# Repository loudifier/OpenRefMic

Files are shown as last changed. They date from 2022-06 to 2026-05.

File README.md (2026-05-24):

# OpenRefMic



OpenRefMic is an open hardware design for a reference microphone that fits in the popular 1/2" reference microphone form factor, works with consumer microphone interfaces, and meets or exceeds the performance of professional reference microphones at a vastly reduced total system cost.

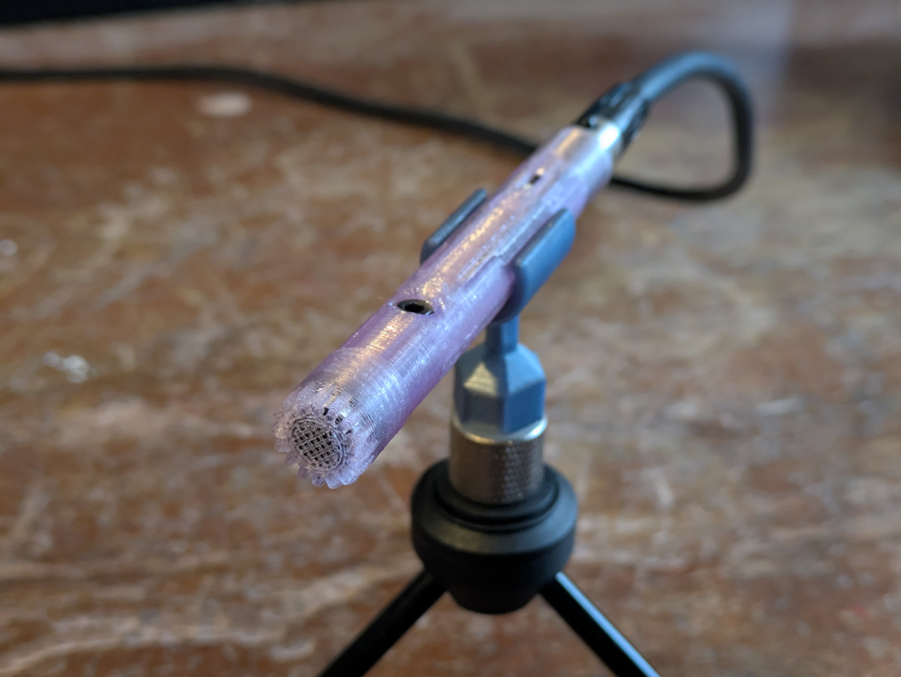
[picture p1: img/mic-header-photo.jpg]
OpenRefMic


<br>

## OpenRefMic v2

OpenRefMic version 2 significantly improves the usability of the mic, with integrated frequency response correction, improved PCB layout, and a simpler and more robust mechanical design.

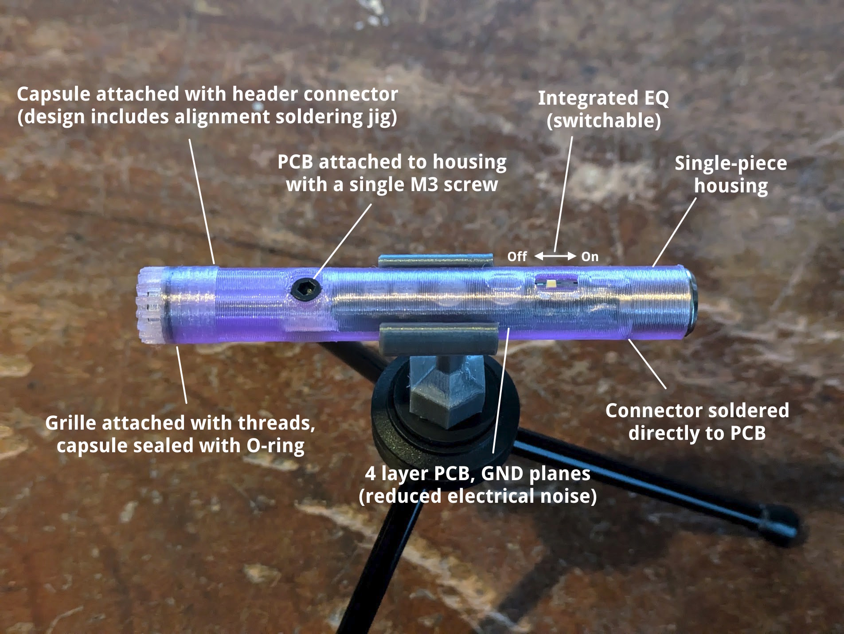
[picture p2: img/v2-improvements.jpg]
v2 improvements


<br>

## Critical specs, typical performance

- Frequency Response: 10Hz-20kHz
    - ±1dB from 10Hz 2.5kHz
    - +4-7dB 10Hz-20kHz raw capsule response
    - ±2dB 10Hz-20kHz with integrated EQ filter
- Noise Floor: 17dBA
- Acoustic Overload Point: 118dBSPL
- Sensitivity: 100mV/Pa
- Dimensions: 12.7x92mm
- Parts cost: $50 (not including 3D printed parts)
- Interface: mini-XLR, 48V phantom power

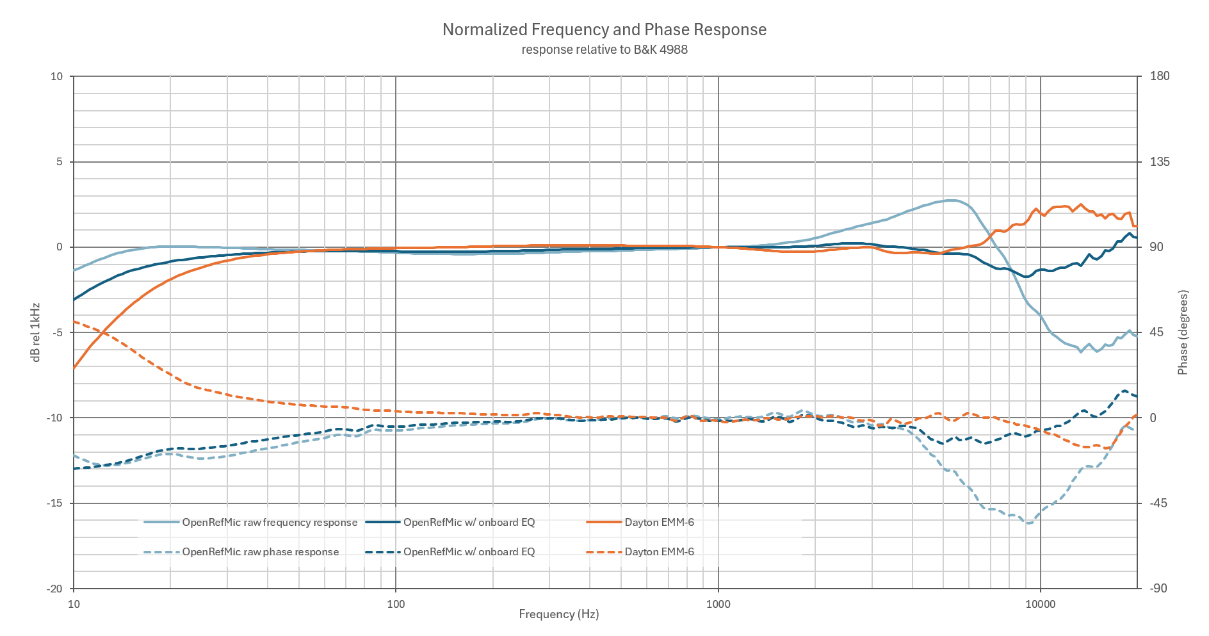
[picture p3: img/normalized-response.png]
normalized frequency response


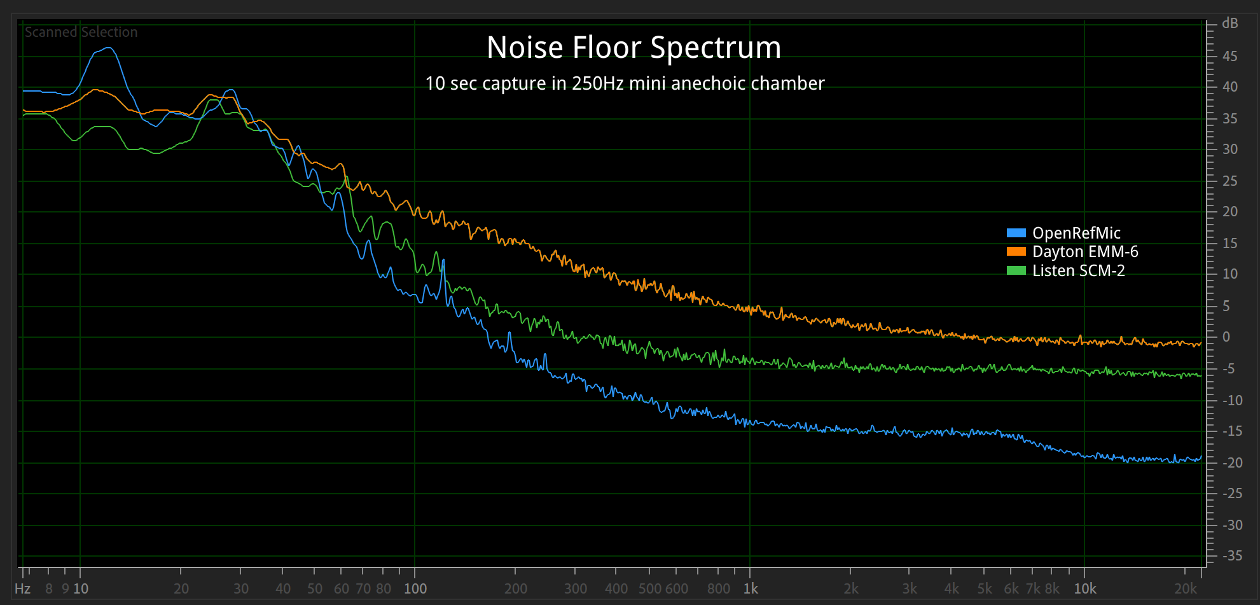
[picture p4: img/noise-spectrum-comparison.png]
noise floor spectrum


<br>

### 1/2" microphone comparison

| Mic | Interface | Frequency Response (20-20k) | Noise Floor | AOP | Price |
|---|---|---|---|---|---|
| OpenRefMic | 48V phantom power, mini XLR | +3/-7dB (±2dB with EQ) | 17dBA | 118dBSPL | Typically <$60 |
| Dayton EMM-6 | 15-48V phantom power, XLR | ±2dB | 36dBA | 127dBSPL | $60 |
| MiniDSP U-MIK 2 | USB-C | Not specified (likely ±2dB) | 20dBA | 125dBSPL | $195 + import |
| PCB 376A32 | 12-48V phantom power, XLR | ±2dB | 15.5dBA | 137dBSPL | $1,445 |
| B&K 4191 | 200V Lemo | <±1dB | 20dBA | 162dBSPL | Ask for price ($$$) |
| GRAS 46AE | CCP BNC | ±2dB | 17dBA | 138dBSPL | Ask for price ($$$) |

<br>

## Project Overview
The core of the OpenRefMic design is a preamplifier that biases an electret microphone from 48V phantom power, buffers the microphone signal, applies a frequency response correction filter, and to sends the signal to a standard microphone interface. The circuit was designed for the [PUI AOM-5024L-HD-F-R](https://puiaudio.com/file/specs-AOM-5024L-HD-F-R.pdf) low noise microphone capsule, and has been built and tested with that part, but should work with most other electret mics. The schematic and PCB layout were designed in KiCAD and are available in the [Preamplifier section](preamplifier/PREAMPLIFIER.md) of the project, along with the [BOM for all electrical and mechanical parts](Bill_of_materials.csv).

<br>

OpenRefMic construction is simple, consisting of a 3D printed housing, the PCB, mic capsule, screw/nut, and optionally an O-ring and dab of UV cure glue. CAD in Fusion360 and STEP formats are in the [Assembly section](assembly/ASSEMBLY.md), along with STLs for the printed parts and a step-by-step construction guide.

<br>

The noise performance of the complete OpenRefMic prototype far exceeds that of comparably-priced measurement microphones, with a flat frequency response suitable as a reference microphone for measuring speakers, distortion, noise emissions, and capturing field recordings. Raw measurement data, compensation curves, and recommendations for applying calibrations to measurements and recordings are in the [Calibration section](calibration/CALIBRATION.md).

<br>

## Project Goals

### Low noise

This is the most important factor of the OpenRefMic project, and all of the other performance metrics and goals are considered "nice to have". While there are several popular affordable measurement microphones on the market (like the Dayton EMM-6), their noise performance ranges from mediocre to poor. Even professional reference microphones tend to prioritize frequency response flatness over noise performance, and very low noise reference microphones are prohibitively expensive for the hobbyist or self-funded experimenter. The video below is an example of the dramatic difference in noise performance between OpenRefMic and the Dayton EMM-6.

[field recording noise comparison](https://user-images.githubusercontent.com/23405416/175431344-0c36cc5d-fb55-48f4-8029-bcf0d835c0a0.mp4)

Low noise is obviously helpful for applications like field recordings or measuring low-level noise emissions, but one area where microphone noise floor is often overlooked is in speaker distortion measurements. Increasing the stimulus and analysis window or moving the microphone closer to the speaker can help resolve lower distortion levels, but those options may not always be feasible for the given speaker or test setup. The graph below is an example of the differences that you might see between distortion measurements with a typical budget measurement mic with a ~34dBA noise floor and an OpenRefMic with ~18dBA noise floor.

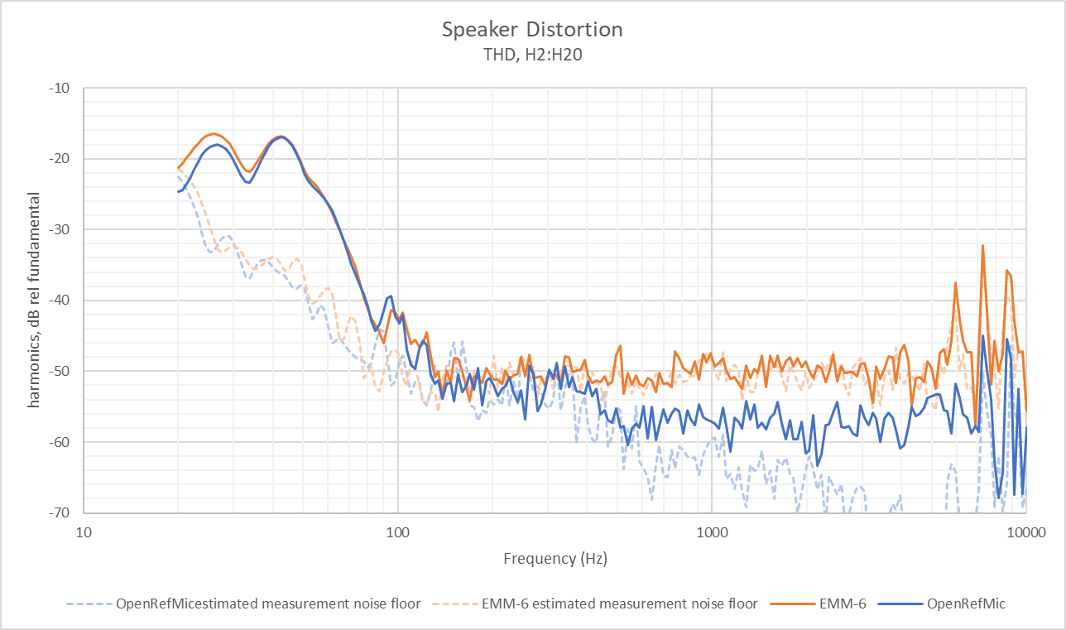
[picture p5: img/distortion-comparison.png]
distortion measurement with OpenRefMic vs EMM-6


<br>

### Flat, omnidirectional frequency response

A reference microphone should have a frequency response that is flat or characterized well enough that it can be understood how measurements and recordings relate to absolute physical constants. Some aberrations in the off-axis response is expected, particularly at very high frequencies, but the design of the housing, porting, and front grille should minimize directional effects as much as possible. In cases where a flat frequency response is not achievable, the response should be characterized and a process should be defined to apply reciprocal filters to correct recordings.

The microphone element in OpenRefMic has a very low noise floor, but it does not have a flat frequency response. See the calibration page for a compensation curve and filter settings to correct measurements and recordings. 

<br>

### Compatibility with "prosumer" audio interfaces

Professional reference microphones typically require interfaces that are uncommon outside of labratory settings. IEPE current loops over BNC cables on the more affordable end of the spectrum and 200V polarization supplied via LEMO connectors at the other end, where the cable itself is often over $500. The pro audio world has instead standardized on balanced signals and phantom powering over cheap XLR cables, and OpenRefMic is designed to achieve high performance with these affordable interfaces.

<br>

### Low cost

Compatibility with consumer-grade microphone interfaces eliminates the prohibitive costs of an IEPE or LEMO interface, but the parts availability and BOM cost of the microphone itself should be comparable to that of measurement microphones that target the DIY speaker building market. The parts needed to build an OpenRefMic are cheap and, with the low prices of desktop 3D printers and PCB fabrication services, many builders will be able to make their own OpenRefMic for less than they would spend on a budget measurement microphone.

<br>

### 1/2" form factor

Many measurement microphones fit a 1/2" cylindrical form factor, or at least have a long probe end with a 1/2" diameter, which helps maintain omnidirectional frequency response up to several kilohertz. Phantom powering necessitates relatively large capacitors, but the OpenRefMic PCB just barely fits within a 1/2" cross-section. Using a mini-XLR connector, the overall microphone dimensions are 12.7x92mm, almost identical to a reference microphone from B&K or GRAS.

Note that the front grille diameter for OpenRefMic v2 is 13.2mm, which is the de facto standard for professional reference microphones. The slightly increased diameter allows enough space to include an O-ring to seal the mic capsule, threads to actually attach the grille to the mic body, and is wide enough to properly seal to a standard 1/2" pistonphone calibrator.

Specialized shapes for specific applications are left up to individual builders, but please share your design if you would like to add additional form factors to the project.

<br>

### Further goals

- The initial design is based around the PUI AOM-5024L-HD-F-R electret microphone capsule, but designs for additional capsules that trade noise performance for frequency response flatness will be added in the future. The preamplifier as-shown should work with a wide variety of electret mics, and component values can be adjusted for optimal performance or compatibility with analog MEMS mics.
- OpenRefMic prototypes have had normalized frequency respone within ±2dB up to 20kHz, which is typical for commercial measurement microphones. However, absolute sensitivity varies by up to ±3dB, which could introduce significant error in SPL measurements. Professional measurement microphones are calibrated in the field with a pistonphone, a device that you insert the microphone tip into, which generates a tone with a precise frequency and sound pressure level that is consistent for a given sealed air volume. If you have any ideas for a device that could replicate this functionality, or otherwise accurately generate or measure a sound pressure level in order to calibrate an OpenRefMic, please reach out.

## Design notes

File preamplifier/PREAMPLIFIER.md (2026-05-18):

# Preamplifier

A high performance mic element determines the majority of the acoustic characteristics of a measurement microphone, but for the hobbyist or experimenter on a budget, actually powering and getting a useful signal from the mic element can be difficult. A power supply with low acoustic and electrical noise is required, as well as a data acquisistion system that can capture the full dynamic range of the transducer, particularly the lowest signal levels. Modern consumer or "pro audio" equipment (not to be confused with "professional" equipment for measuring products under development against telephony standards, for example) is available with excellent performance and very affordable pricing, but cannot directly power an electret mic or get an optimal signal level from it.

The preamplifier is the heart of the OpenRefMic project, powering an electret microphone from a standard 48V phantom power supply, correcting the capsule frequency response, and buffering the mic signal to drive a typical low impedance microphone input.

<br>

## Schematic, layout, project files

The preamplifier schematic in PDF format can be found [here](OpenRefMic_v2-schematic.pdf), and the KiCAD project files and gerbers are [here](ref_mic/gerbers/). The complete bill of materials (including optional and mechanical parts) is [here](../Bill_of_materials.csv).

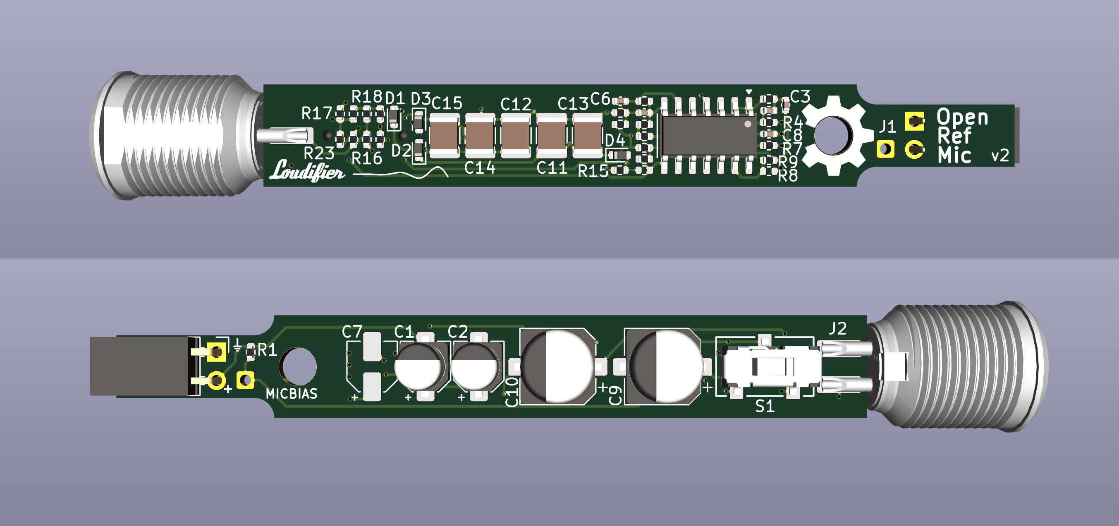
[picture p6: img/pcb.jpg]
PCB


### PCB thickness

Note that the OpenRefMic v2 PCB design uses a mini XLR connector with the terminals soldered to either side of the PCB. A standard 1.6mm/63mil PCB is slightly too thick to fit beteen the terminals of the connector, so a thinner stackup is required. The next common size down from typical vendors like JLCPCB is 1.2mm, which has been tested and works well on the v2 prototype mics.

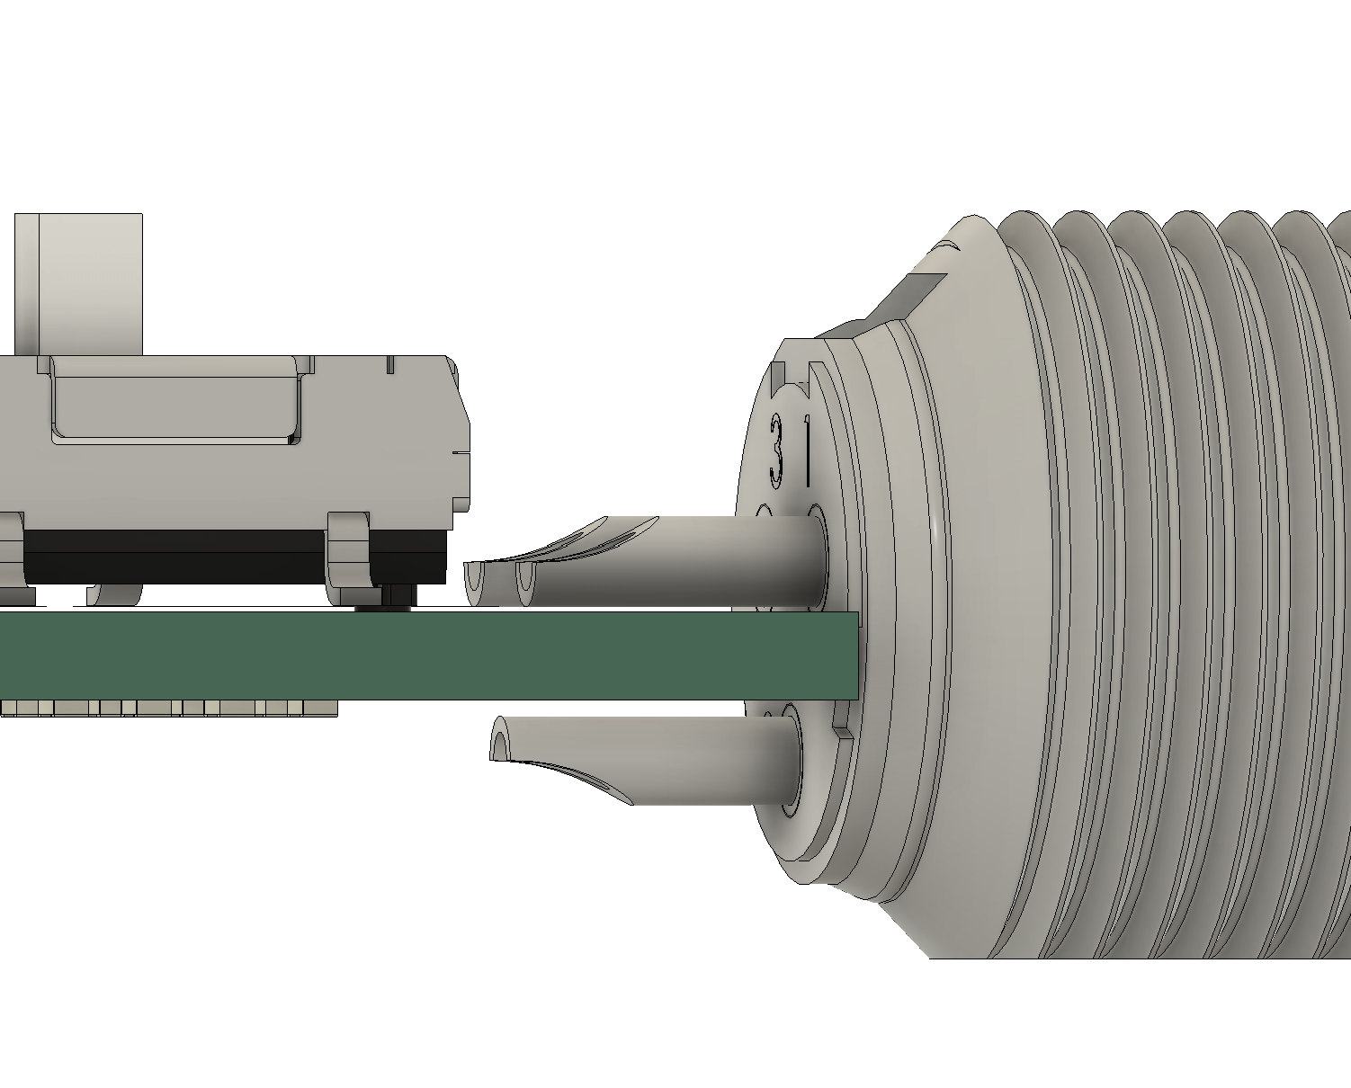
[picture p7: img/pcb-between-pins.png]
PCB between mini XLR connector pins


<br>

## Circuit description

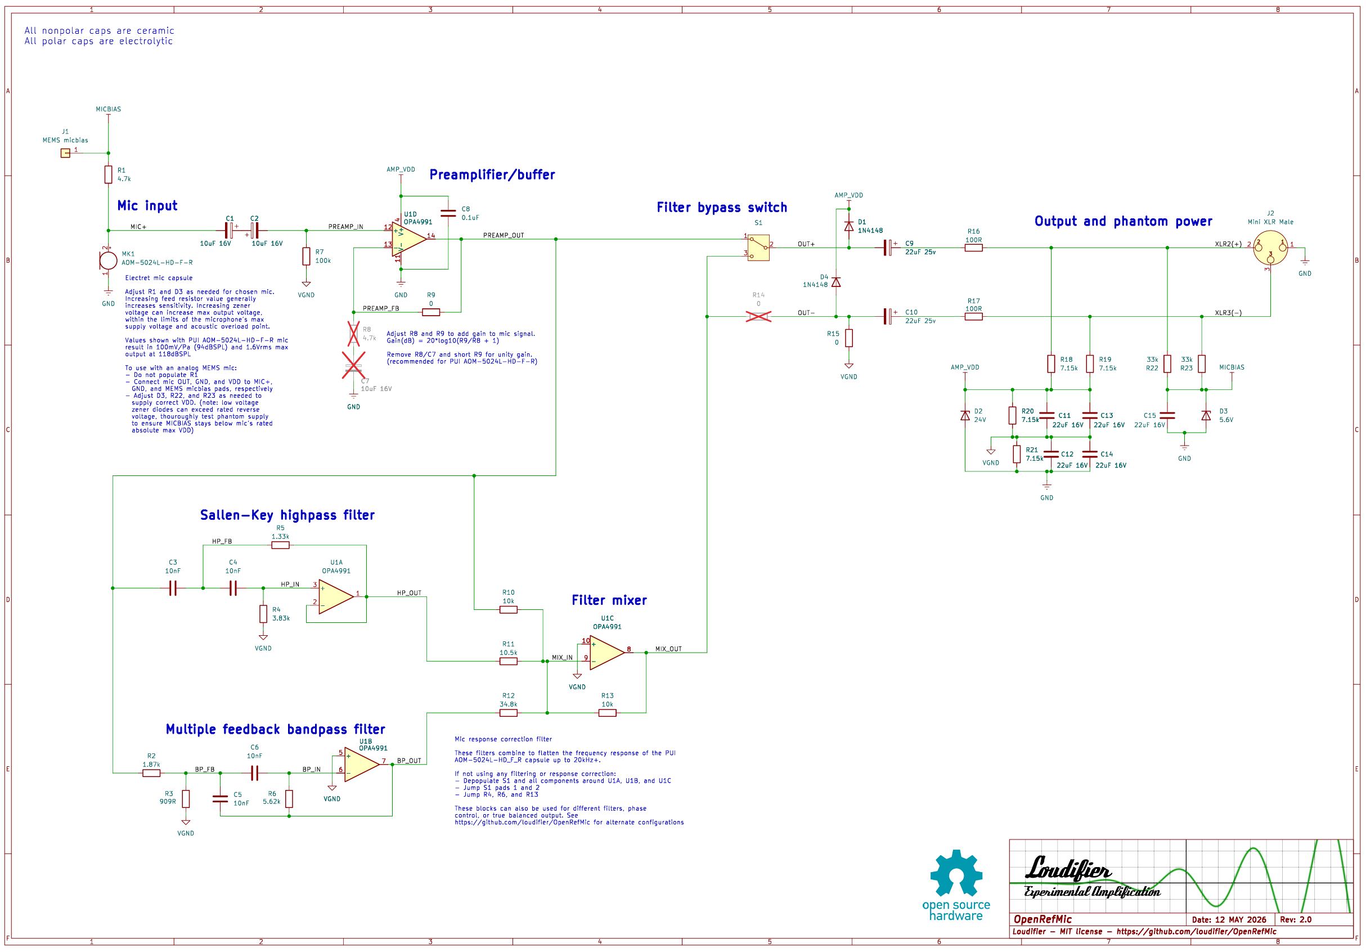
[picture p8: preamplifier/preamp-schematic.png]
preamlifier schematic


### Power

Phantom power is supplied from the host microphone interface in the form of 48VDC connected to each signal line of the balanced cable via 6.81k resistors. The OpenRefMic preamplifier creates two power rails from the phantom power with simple Zener shunt voltage regulators.

The opamp power rail is fed from the phantom power supply through R18 and R19. The actual opamp supply voltage depends on the opamp current draw and the VGND voltage divider formed by R20 and R21, and C11-C14 provide bulk capacitance and low AC impedance for the VGND. OPA4991 is recommended for its low noise and low quiescent current, resulting in an opamp supply rail around 18V. When power is applied, or in the event the opamp current draw is very low or missing, D2 clamps the opamp supply rail to 24V.

D1 and D4 protect the opamp when phantom power is initially applied. When all of the capacitors are discharged and phantom power is turned on, it would briefly apply 48V to the opamp output, until the AC-coupling caps charge up. Instead, the D1 and D4 shunt the voltage at the opamp output to the opamp supply rail, and any voltage at the supply rail over 24V is in turn shunted through D2.

The electret mic bias voltage is fed from the power supply through R22 and R23, with D3 and C15 regulating the shunt voltage.

Electret microphones use a single pin for power input and signal output. They are fairly tolerant of different bias voltages and feed resistances, but ~3V supplied through a 2.2k resistor is common. The feed resistor creates a voltage divider with the microphone's output impedance, so the sensitivity can be increased by increasing the feed resistance. The bias voltage determines the microphone's maximum peak to peak output voltage, so increasing the bias voltage can raise the effective acoustic overload point of the mic. The transducer itself will limit the absolute AOP, but increasing the bias voltage can provide some electrical headroom, particularly when increasing the feed resistance for higher sensitivity.

With 5.6V bias and 4.7k feed resistor, R1, the AOM-5024L-HD-F-R has a voltage sensitivity of about 1V/Pa and an AOP of 118dBSPL. This voltage range matches well with the dynamic range of most microphone inputs, and almost perfectly matches the dynamic range of the popular Focusrite Scarlett 2i2 mic input at the minimum gain setting.

### Buffer and balanced output

An opamp is not strictly necessary to connect the output of an electret mic to a microphone input, but some sort of buffer is needed if you want to maintain a balanced output impedance and high rejection ratio for any common mode noise that is picked up in the cabling. Buffering the signal also avoids loading the electret mic output with the low impedance input of the microphone interface.

U1D is configured as a unity gain buffer. C1 and C2 AC-couple the electret mic signal to the opamp input, and R7 provides DC bias. The mic bias supply and VGND bias may be around the same DC voltage, so C1 and C2 are arranged with opposing polarities to form a nonpolar cap. To increase the buffer gain, increase the value of R9 and populate R8 and C7. To avoid low frequency roll off, the value of R8 should not be reduced below 4.7k.

C9 AC-couples the opamp (or filter mixer) output. 22uF ensures flat frequency response below 10Hz with low impedance microphone interfaces. R16 provides some isolation from the opamp output and capacitive cable loads.

R15, C10, and R17 appear useless at first glance, but are present to match the impedance of the noninverting output. This is not true differential signaling, but it is technically balanced, often called pseudodifferential. As long as both noninverting and inverting signal lines are terminated with matched impedances, EMI picked up by the cable will be equal on both lines and will be canceled by the microphone input.

### Frequency response correction filters

The AOM-5024L-HD-F-R mic capsule has a very low noise floor, but deviates from a flat frequency response at higher frequencies. This response is fairly consistent, and can be corrected to within a couple dB of flat with a carefully arranged filter network. That correction can often be applied as a postprocessing step (see [calibration](../calibration/CALIBRATION.md)), but v2 of the OpenRefMic preamplifier includes an analog filter netowrk that can correct the response for situations where postprocessing is cumbersome or impossible.

The AOM-5024L-HD-F-R response has a resonant peak around 5.5kHz with an attenuated high shelf that flattens out above 14kHz. The high shelf response is corrected by summing a highpassed copy of the micropohne signal (which has inverted polarity at high frequencies) with the unfiltered microphone signal. That leaves a notch in the response, which is corrected by adding an additional bandpassed copy of the signal.

<!--TODO: add graphs for raw and corrected response and individual filters-->

The highpass response is realized with a Sallen-Key filter around U1A, and the bandpass response is formed by a multiple feedback bandpass filter around U1B. U1C acts as an inverting mixer, with R10-R13 adjusting the gain/mixing ratios of the filtered and unfiltered signals. This means the phase of the overall microphone response with frequency response correction is inverted, relative to the microphone capsule phase. This is usually easily corrected with a single button in hardware or software interfaces designed to receive microphone input.

The exact filter parameters and component values were arrived at through simulation, filter calulators, and an optimization script to fit the filters to a target correction curve. See the [calibration section](../calibration/CALIBRATION.md) for details on the filter optimization process.

S1 allows selection between the raw microphone signal and the microphone signal with frequency response correction applied.

## Alternate filter configurations
note: these screenshots were made with an earlier version of the schematic that used incorrect filter component values

### No filter, true balanced output
If you are using the OpenRefMic preamplifier with a different mic capsule that does not need frequency response correction, you can eliminate the filter blocks and filter bypass switch.

- Remove S1, and jump S1 pads 1 and 2
- Most of the components around U1A, U1B, and U1C are not necessary, but R4, R6, and R13 should be populated to avoid unpredictable behaviour

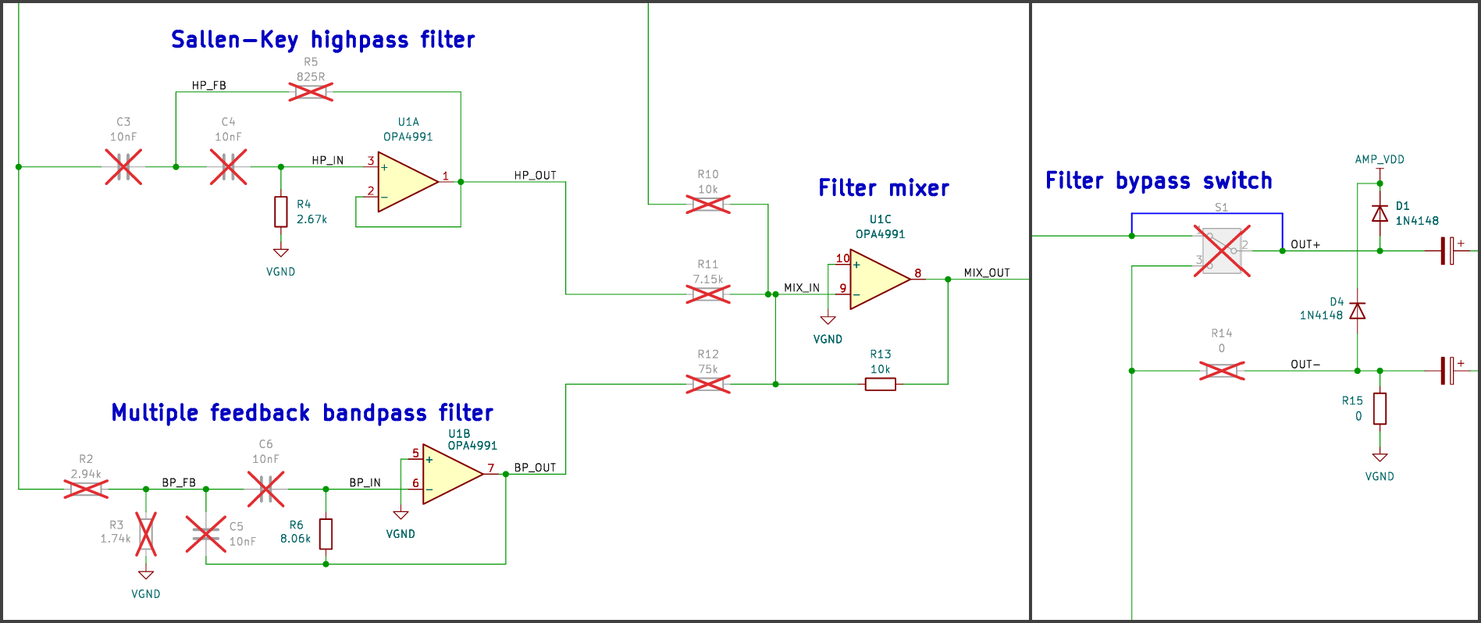
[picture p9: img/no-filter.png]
No filter


To add an inverted signal for true balanced ouptut:

- Remove R11, R12, and R15
- Populate R10, R13, and R14

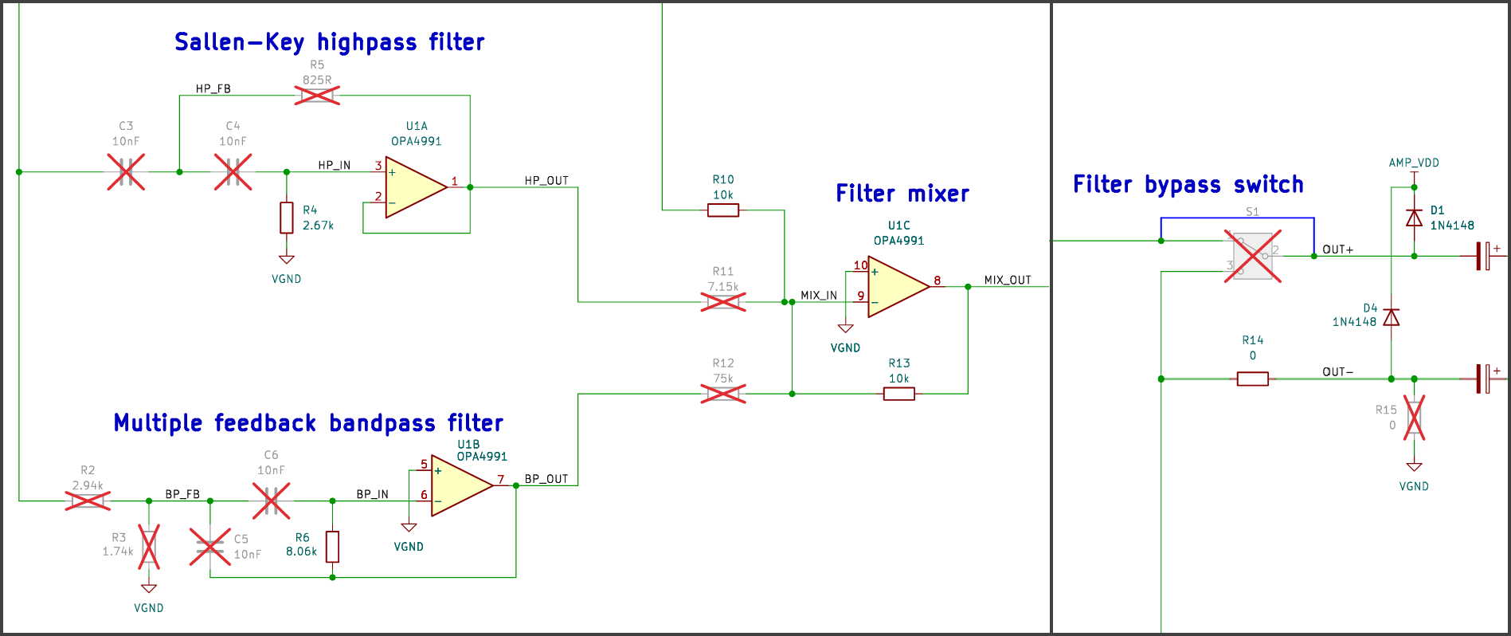
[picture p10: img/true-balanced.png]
True balanced output


Note that the effective ouptut amplitude is 6dB higher with balanced output, so you may need to reduce the value of R1 and/or voltage of D3 to ensure sufficient headroom with your micropohne interface.

### Phase switch

If you need phase control more than frequency response correction, S1 can repurposed to select between noninverted and inverted output.

- Remove R11 and R12

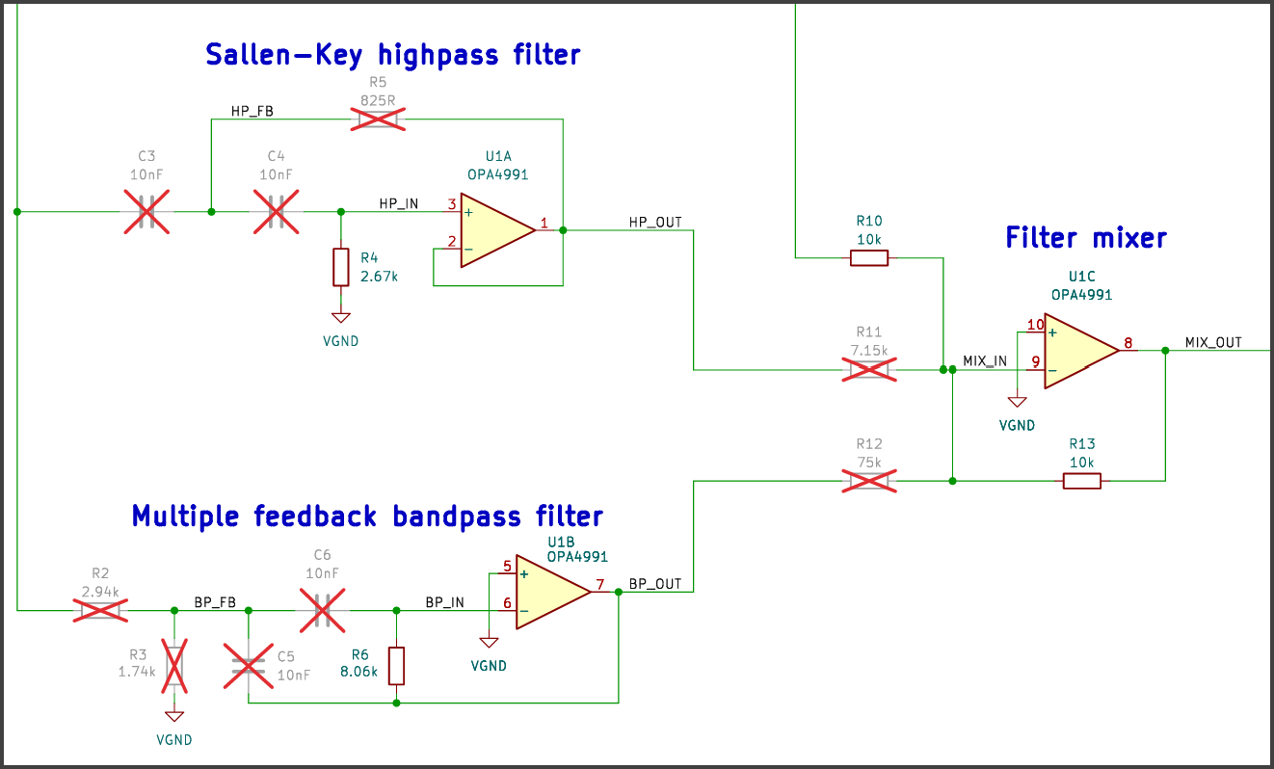
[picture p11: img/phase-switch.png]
Phase inversion switch


### Rumble filter

For a switchable highpass filter to remove rumble below 100Hz:

- Remove R10 and R11
- Replace R6 with a 330k resistor
- Replace R3 with a 75k resistor
- Replace R2 with a 10nF capacitor
- Replace R12 with a 10k resistor

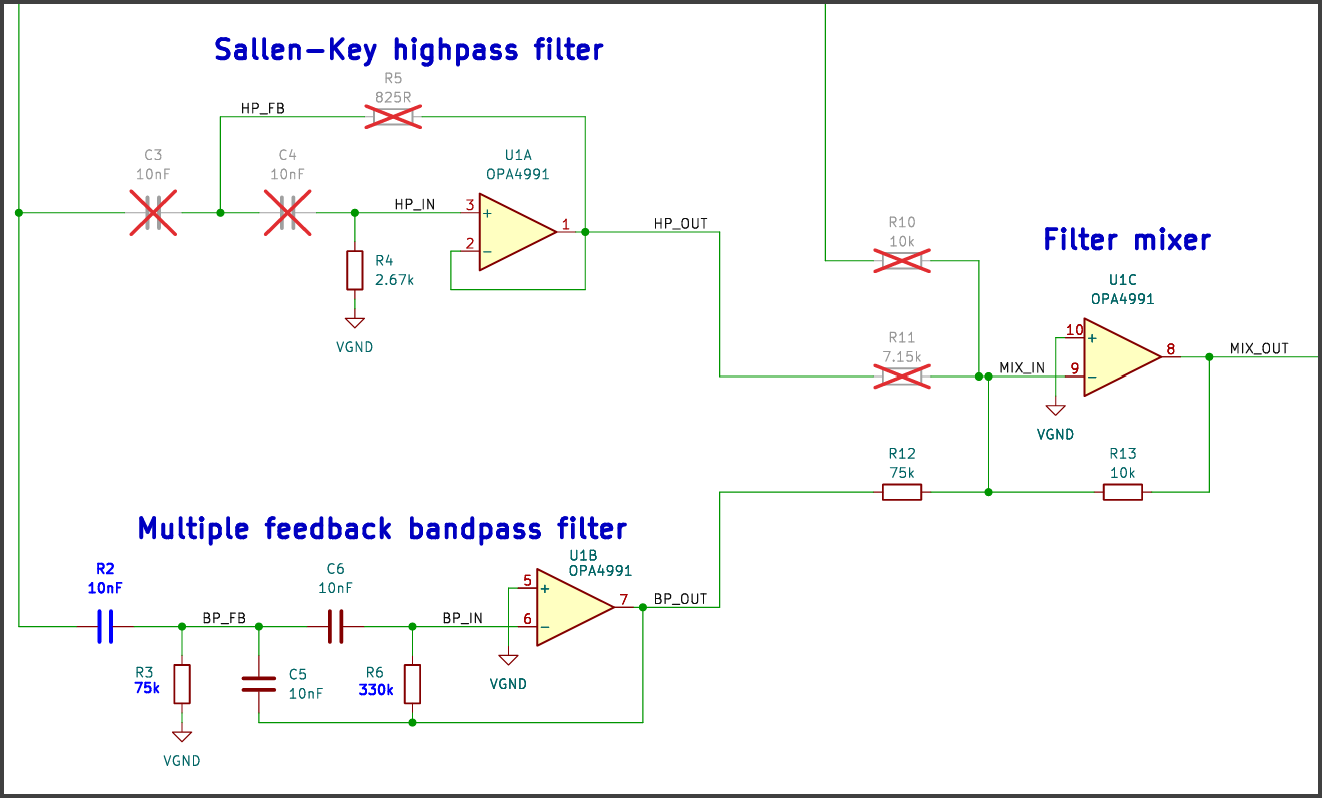
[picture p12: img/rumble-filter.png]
Rumble filter


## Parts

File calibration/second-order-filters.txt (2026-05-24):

2nd order filters to correct OpenRefMic recordings

96kHz Filter parameters
High Shelf
freq: 8291
Q: 0.978
gain: 5.54

Peaking EQ
freq: 4932
Q: 1.029
gain: -3.05

96kHz Biquad filter coefficients
High Shelf
a0	1
a1	-1.240981611
a2	0.536671857
b0	1.70667411
b1	-2.480292285
b2	1.069308421

Peaking EQ
a0	1
a1	-1.602317261
a2	0.689581899	
b0	0.954039842
b1	-1.602317261
b2	0.735542057

48kHz Filter parameters
High Shelf
freq: 6180
Q: 1.323
gain: 5.94

Peaking EQ
freq: 7314
Q: 1.149
gain: -6.12

48kHz Biquad filter coefficients
High Shelf
a0	1
a1	-0.903894843
a2	0.532359656
b0	1.69313323
b1	-2.09951966
b2	1.034851243

Peaking EQ
a0	1
a1	-0.764417706
a2	0.327926396
b0	0.83006978
b1	-0.764417706
b2	0.497856615

44.1kHz Filter parameters
High Shelf
freq: 6135
Q: 1.295
gain: 5.89

Peaking EQ
freq: 5500
Q: 1.2
gain: 5.5

44.1kHz Biquad filter coefficients
High Shelf
a0	1
a1	-0.800182225
a2	0.506962568
b0	1.659071224
b1	-1.919324185
b2	0.967033304

Peaking EQ
a0	1
a1	-0.663683189
a2	0.293674991
b0	0.820807586
b1	-0.663683189
b2	0.472867406

16kHz Filter parameters
High Shelf
freq: 7521
Q: 0.888
gain: 13.72

Peaking EQ
freq: 4792
Q: 0.631
gain: -3.33

16kHz Biquad filter coefficients
High Shelf
a0	1
a1	1.851899488
a2	0.86692061
b0	1.094511024
b1	1.822962161
b2	0.801346913

Peaking EQ
a0	1
a1	0.319816173
a2	0.045056489
b0	0.847950826
b1	0.319816173
b2	0.197105663

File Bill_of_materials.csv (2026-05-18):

Electrical components
Reference | Value | Qty | DNP | DigiKey_Part_Number | LCSC_Part_Number | Comment
C1,C2 | 10uF 16V | 2 |  | UZG1C100MCL1GB | Lelon VSS100M1CTR-0404
C3,C4,C5,C6 | 10nF | 4 |  | CC0402KRX7R9BB103 | YAGEO CC0402KRX7R9BB103
C7 | 10uF 16V | 1 | DNP | UZG1C100MCL1GB | Lelon VSS100M1CTR-0404 | Populate R8 and C7 to increase gain
C8 | 0.1uF | 1 |  | CC0402KRX5R9BB104 | YAGEO CC0402KRX5R9BB104
C9,C10 | 22uF 25v | 2 |  | UZG1E220MCL1GB | Nichicon UZG1E220MCL1GB
C11,C12,C13,C14,C15 | 22uF 16V | 5 |  | EMK325BJ226MD-T | Taiyo Yuden EMK325BJ226MD-T
D1,D4 | 1N4148 | 2 |  | 1N4148X-TP | MCC 1N4148X-TP
D2 | 24V | 1 |  | BZT585B24T-7 | Diodes Incorporated BZT585B24T-7 | Zener diode
D3 | 5.6V | 1 |  | BZT52C5V6T-7 | Diodes Incorporated BZT52C5V6T-7 | Zener diode
J2 | Mini XLR Male, panel mount | 1 |  | TB3M | Switchcraft TB3M (not normally stocked) | Significantly cheaper no-name alternatives available on Amazon/AliExpress
MK1 | AOM-5024L-HD-F-R | 1 |  | AOM-5024L-HD-F-R | PUI Audio, Inc. AOM-5024L-HD-F-R (not normally stocked)
R1 | 4.7k | 1 |  | RC0402FR-074K7L | YAGEO RC0402FR-074K7L
R8 | 4k7 | 1 | DNP | RC0402FR-074K7L | YAGEO RC0402FR-074K7L | Populate R8 and C7 to increase gain
R2 | 1.87k | 1 |  | RC0402FR-131K87L | YAGEO RC0402FR-131K87L
R3 | 909R | 1 |  | RC0402FR-07909RL | YAGEO RC0402FR-07909RL
R4 | 3.83k | 1 |  | RC0402FR-073K83L | YAGEO RC0402FR-073K83L
R5 | 1.33k | 1 |  | RC0402FR-131K33L | YAGEO RC0402FR-131K33L
R6 | 5.62k | 1 |  | RC0402FR-075K62L | YAGEO RC0402FR-075K62L
R7 | 100k | 1 |  | RC0402FR-07100KL | YAGEO RC0402FR-07100KL
R9,R15 | 0 | 2 |  | RC0402JR-070RL | YAGEO RC0402JR-070RL
R14 | 0 | 1 | DNP | RC0402JR-070RL | YAGEO RC0402JR-070RL | When not using correction filtering, R14 can be populated for true balanced output (see OpenRefMic project repository for alternate configurations)
R10,R13 | 10k | 2 |  | RC0402FR-0710KL | YAGEO RC0402FR-0710KL
R11 | 10.5k | 1 |  | RC0402FR-0710K5L | YAGEO RC0402FR-0710K5L
R18,R19,R20,R21 | 7.15k | 4 |  | RC0402FR-077K15L | YAGEO RC0402FR-077K15L
R12 | 34.8k | 1 |  | RC0402FR-0734K8L | YAGEO RC0402FR-0734K8L
R16,R17 | 100R | 2 |  | RC0402FR-07100RL | YAGEO RC0402FR-07100RL
R22,R23 | 33k | 2 |  | RC0402FR-0733KL | YAGEO RC0402FR-0733KL
S1 | CL-SB-12B-01T | 1 |  | CL-SB-12B-01T | Nidec CL-SB-12B-01T | Switch, single pole double throw
U1 | OPA1664 | 1 |  | OPA1664AIDR | TI OPA1664AID | Can substitute with other quad opamp with SOIC-14 package and <~4mA total quiescent current
-- | 1x2 2.54mm RA female header | 1 |  | PPPC021LGBN-RC | CJT(Changjiang Connectors) A2541HWR-2P | Install in MK1 pads on PCB
-- | 1x2 2.54mm RA male header | 1 |  | 10129379-902002BLF | XFCN PZ254R-11-02P | Plug into female header, align mic capsule, and solder male pins to mic capsule (see assembly instructions)
Mechanical components | Part | Qty |  | McMaster_Part_Number |  | Comment
 | M3x8 screw | 1 |  | 91290A113
 | M3 nut | 1 |  | 98676A100
 | 10.5x1.0mm O-ring | 1 |  | 9262K612 |  | Fit into groove on interior surface of grille, seals around outside of mic capsule
3D Printed components | Part | Qty
 | Mic body | 1
 | Grille | 1
 | Top spacer | 1
 | Bottom spaker | 1
Mini XLR adapter cable | Part | Qty |  | DigiKey_Part_Number | LCSC_Part_Number | Comment
 | Mini XLR Female, cable mount | 1 |  | TA3FLX | Switchcraft TA3FLX (not normally stocked) | replace full size female connector on standard XLR cable to build a mini XLR adapter cable. Significantly cheaper no-name alternatives available on Amazon/AliExpress

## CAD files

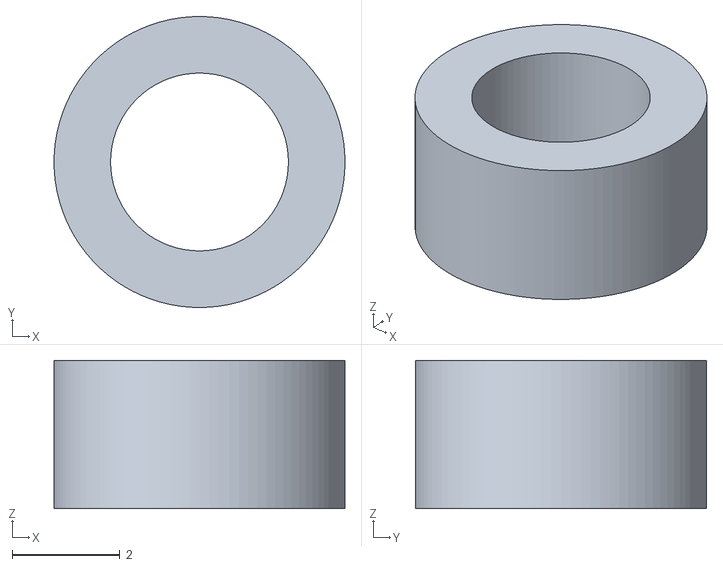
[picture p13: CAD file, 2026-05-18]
assembly/stl/top spacer.stl
5.40 x 5.40 x 2.75

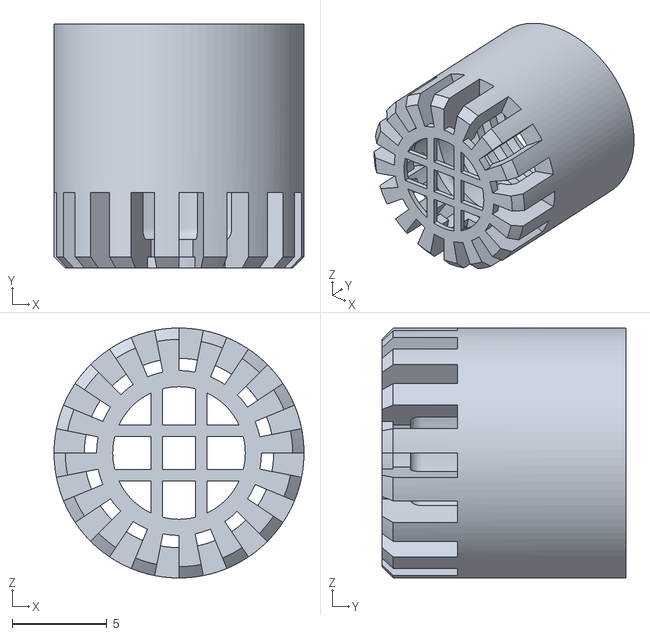
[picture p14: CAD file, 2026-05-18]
assembly/stl/Grille.stl
13.2 x 12.9 x 13.2

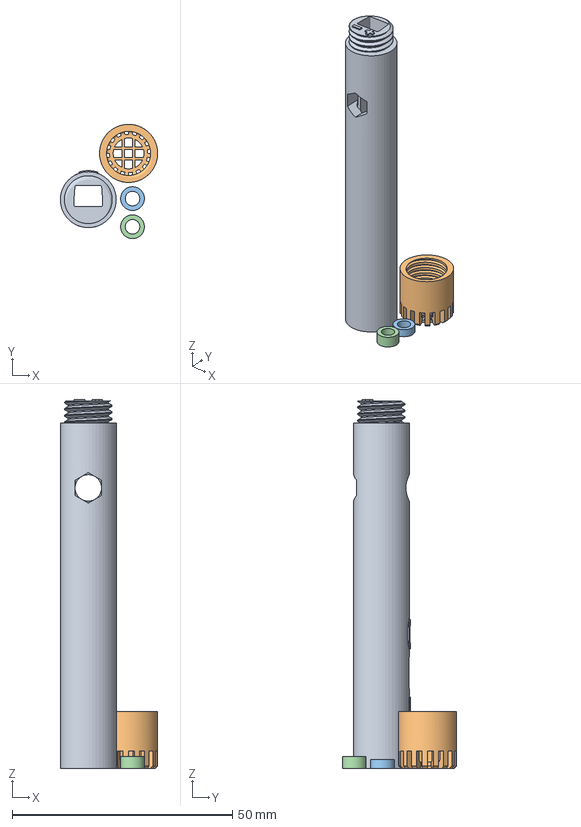
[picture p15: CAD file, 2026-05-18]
assembly/stl/print settings.3mf
22.1 x 26.0 x 83.8 mm
Body.stl
Grille.stl
bottom spacer.stl
top spacer.stl

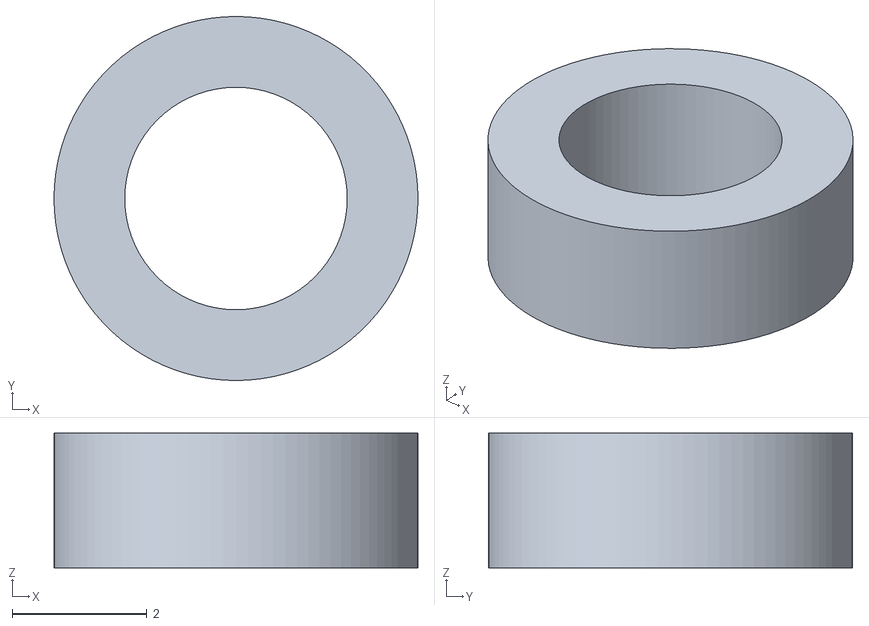
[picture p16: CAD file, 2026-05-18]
assembly/stl/bottom spacer.stl
5.40 x 5.40 x 2.00

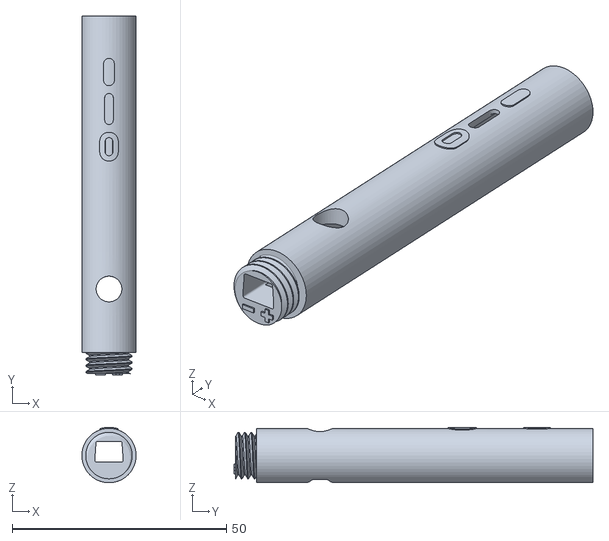
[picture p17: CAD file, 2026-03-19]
assembly/stl/Body.stl
12.7 x 83.8 x 12.9

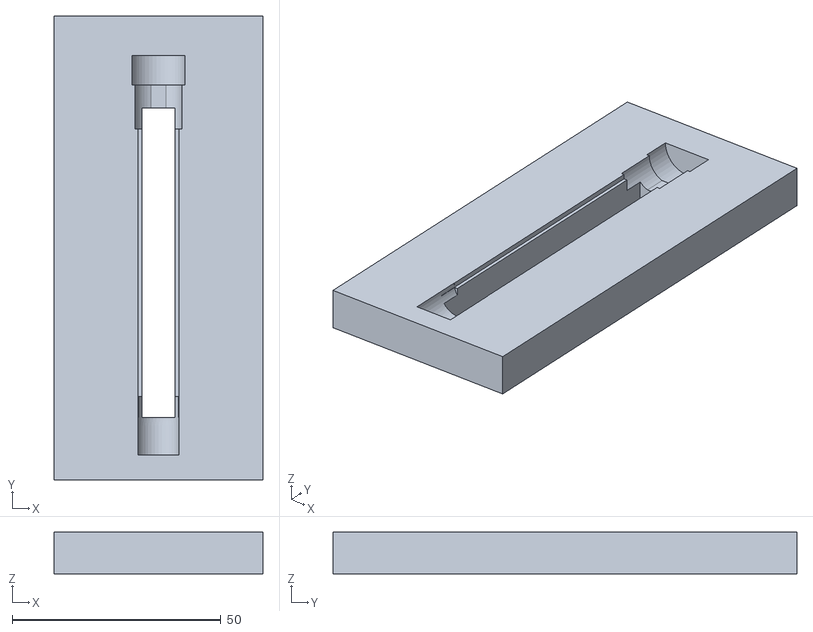
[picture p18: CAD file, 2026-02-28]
assembly/stl/solder-jig.stl
50.0 x 111.0 x 10.0

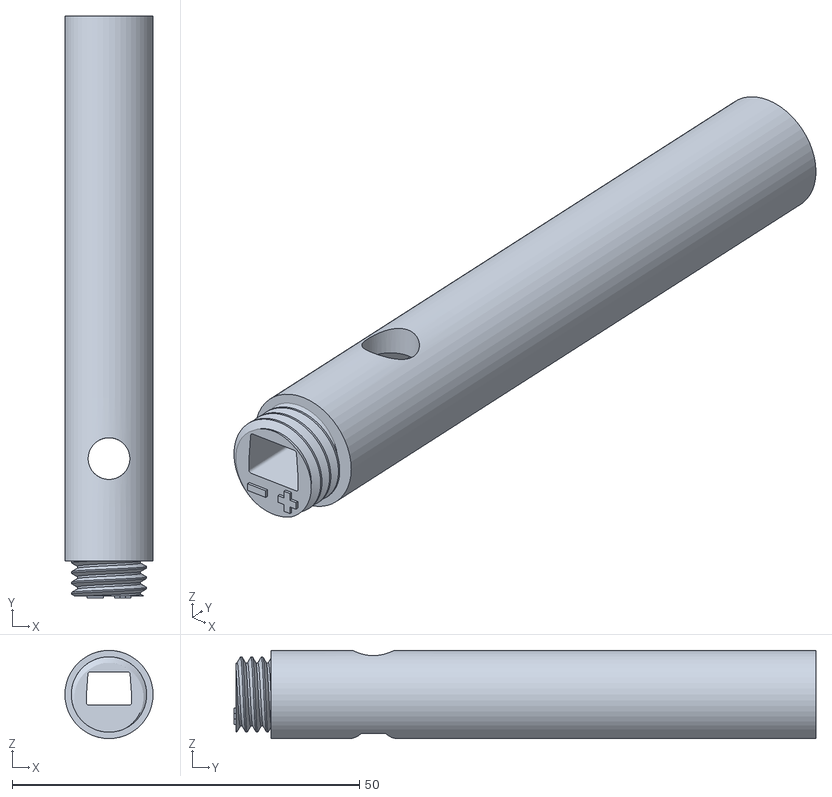
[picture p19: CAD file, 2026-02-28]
assembly/stl/Body_no_switch.stl
12.7 x 83.8 x 12.7

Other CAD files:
assembly/OpenRefMic_v2.f3d

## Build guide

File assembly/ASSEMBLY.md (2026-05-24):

# Construction

The OpenRefMic design consists of an electret microphone capsule, preamplifier PCB, a single screw and nut, an O-ring, glue, and a few 3D printed parts designed to be printed on a regular consumer 3D printer.

## CAD files

STLs for the printed parts are [here](stl/). If you want to modify the design or adjust tolerances for printing, the Fusion360 design file is [here](OpenRefMic_v2.f3d), and a generic STEP file of the complete OpenRefMic assembly is [here](OpenRefMic_v2.step)

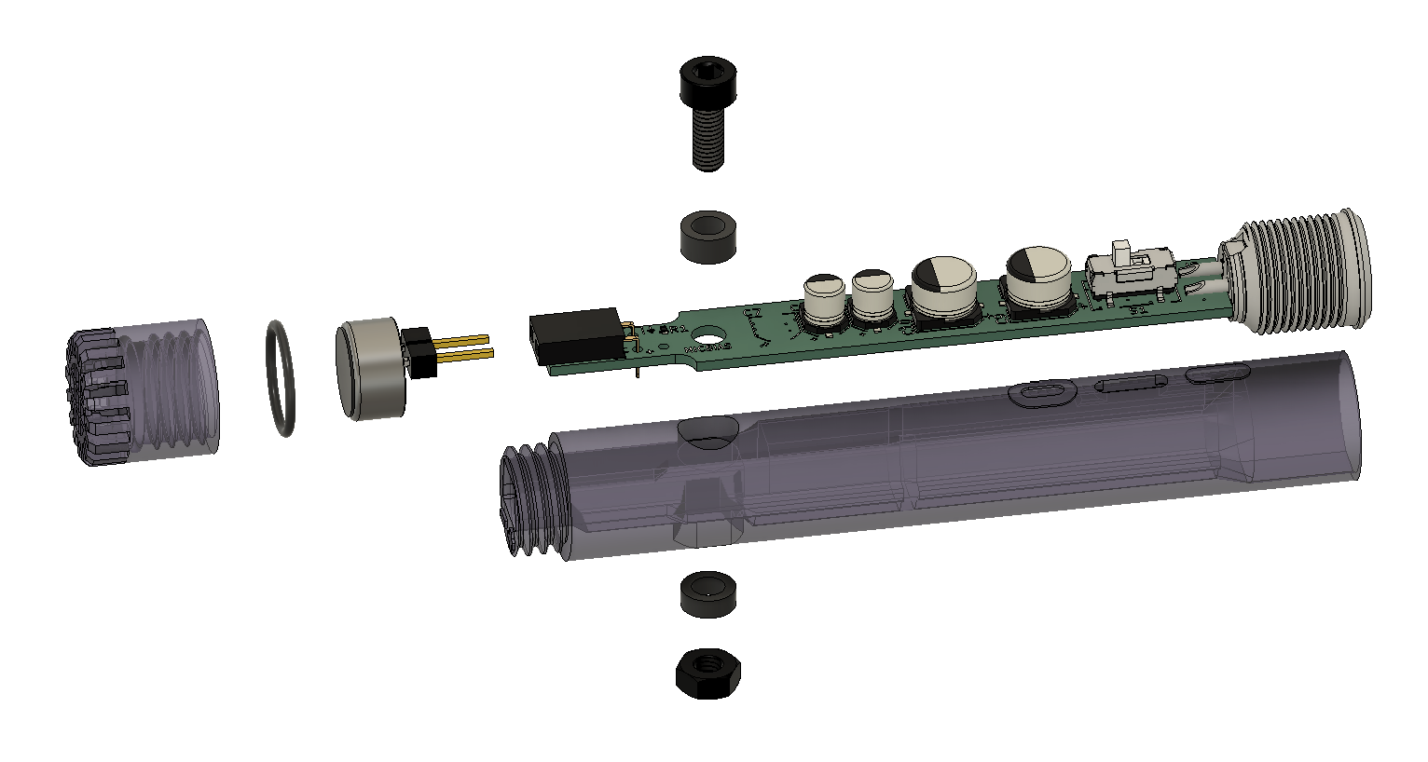
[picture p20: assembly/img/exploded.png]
OpenRefMic exploded view


<br>

## Assembly Guide

There is a [soldering jig](stl/solder-jig.stl) included with the stl files that holds the PCB, mini XLR connector, and mic capsule in the correct position for soldering. It can also be helpful for the initial PCB assembly. It isn't strictly required, but is strongly recommended, particularly when attaching pins to the mic capsule.

### 1. Assemble the PCB

Starting with a bare PCB and components, install all of the components on the PCB except for the mini XLR connector and female header. [The interactive BOM](../preamplifier/OpenRefMic_v2-interactive_BOM.html) can be very helpful for this process.

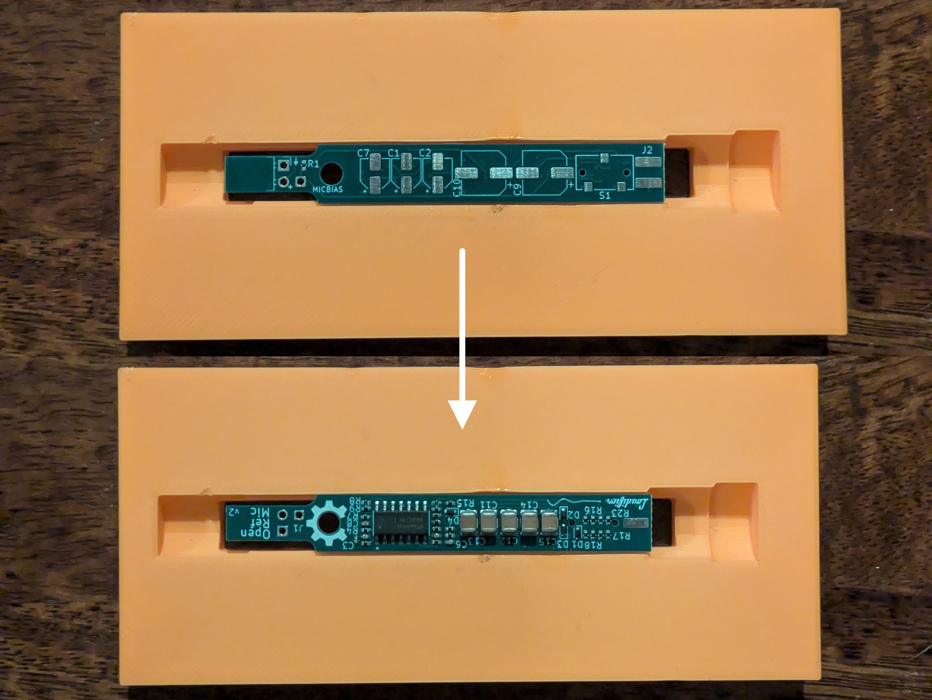
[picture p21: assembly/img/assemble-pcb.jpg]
assemble PCB


<br>

### 2. Install the mini XLR connector

Seat the PCB in the soldering jig with the electrolytic caps and switch facing up, and place the mini XLR connector in the jig with the flat spot facing down. Push the PCB all the way in between the pins of the connector, make sure the pins are centered on the pads, and solder the pins to the pads on the PCB. Then flip the board over and solder the third connector pin to the pad on the bottom of the PCB.

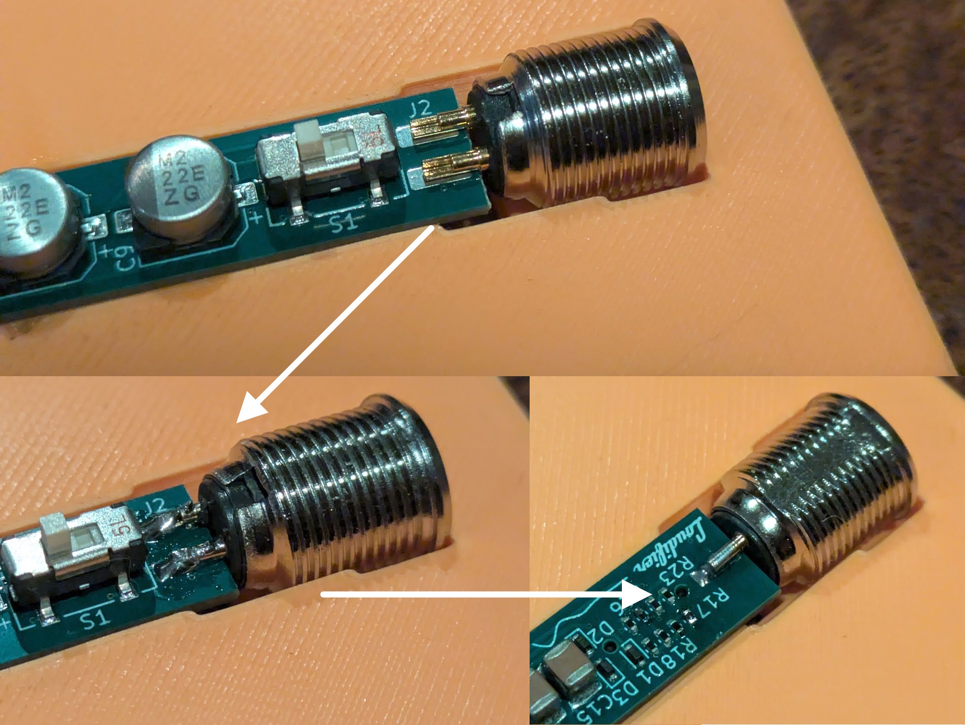
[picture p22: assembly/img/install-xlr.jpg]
install mini XLR connector


<br>

### 3. Install the female header

Install the female header on the same side of the PCB as the electrolytic caps and switch. Solder the pins in place, then flip the board over and trim any excess length off the pins.

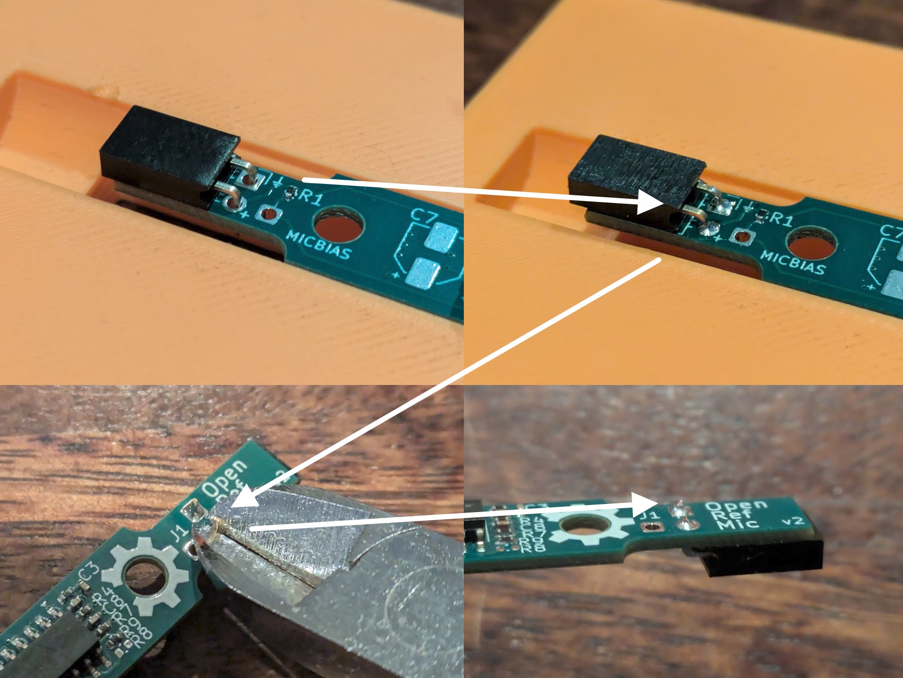
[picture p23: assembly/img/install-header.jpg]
install female header on PCB


<br>

### 4. Add pins to the mic capsule

Insert the right angle male header pins into the female header with the angled pins pointing down. Place the mic capsule in the soldering jig and align the pads with the header pins. Make sure the mic polatity matches the markings on the PCB. Push the PCB and header pins all the way up to the pads on the mic capsule, then solder the pins to the capsule.

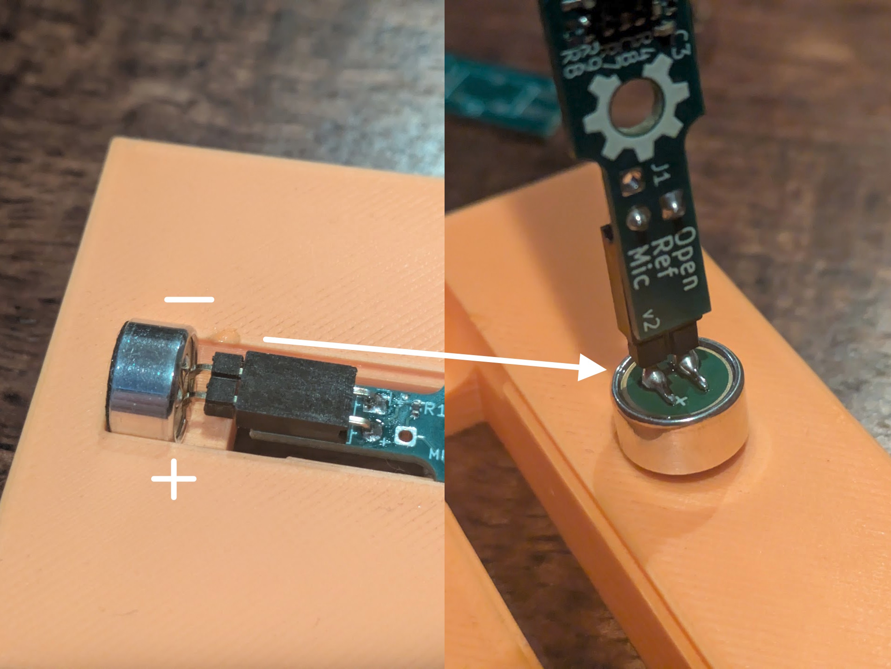
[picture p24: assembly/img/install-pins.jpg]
install pins on mic capsule


<br>

### 5. Reinforce capsule pins

If you plan on not sealing the mic capsule to the grille then this step is not strictly necessary, but it is still recommended to minimize the risk of the pads on the back of the capsule getting ripped off if you take the mic apart for repairs. Adding enough glue to the back of the mic capsule to encapsulate the solder joints adds significant strength to the connection between the pins and the capsule body.

Viscous (sometimes called "gel") super glue/cyanoacrylate can work, but tends to off gas in a way that can leave a residue on nearby surfaces, including potentially clogging up the openings on the mesh covering the front of the mic capsule. UV glue is recommended because it is similarly easy to work with, cures instantly, and usually gives off very few fumes. Add drops of glue on the back of the mic capsule around the solder joints and build it up in layers. The glue should form a taper from the back of the mic capsule up to the plastic part of the header pins. Be careful to not to get glue on the outer edge of the capsule, or it won't fit properly inside the grille.

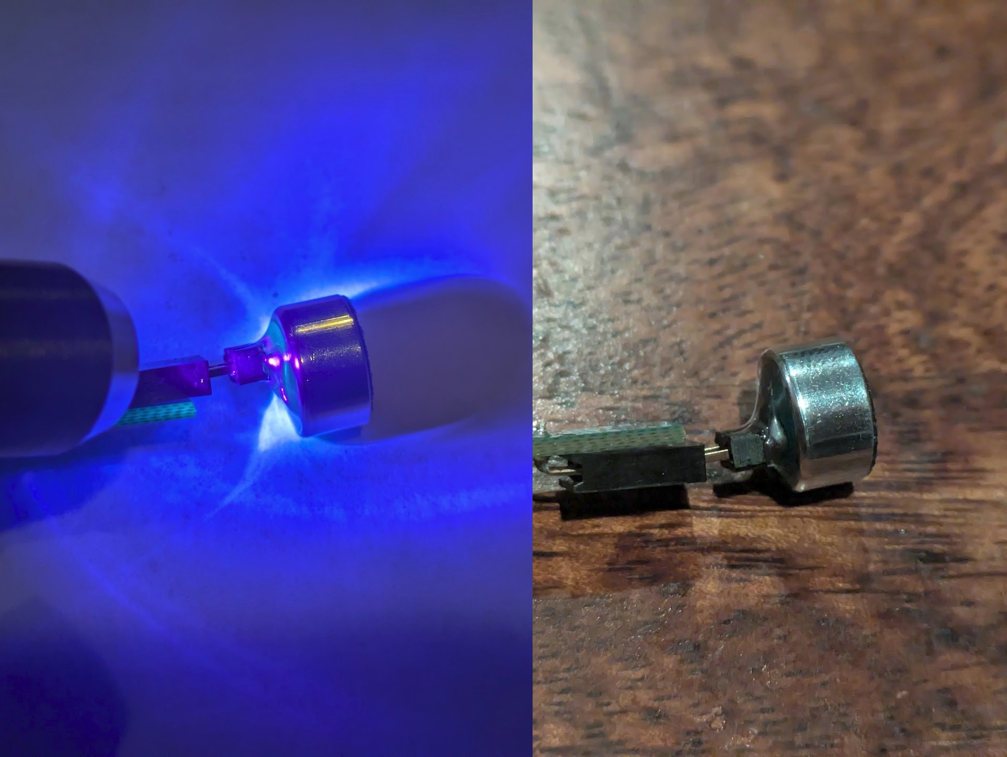
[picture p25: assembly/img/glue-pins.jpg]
reinforce capsule pins


### 6. Print the mic body, grille, and spacers

A filament and print settings that result in strong layer bonding are recommended for best results. The prototype microphone parts were printed on a stock Prusa MK3 printer with no supports, regular PETG filament, 0.15mm layer height, and the number of perimeters increased for effectively 100% concentric infill. You may need to adjust some print settings or tolerances in the CAD files so the parts fit together well. [print settings.3mf](stl/print%20settings.3mf) is a PrusaSlicer project file containing all of the 3D printed components and the print settings used to build the v2 prototypes.

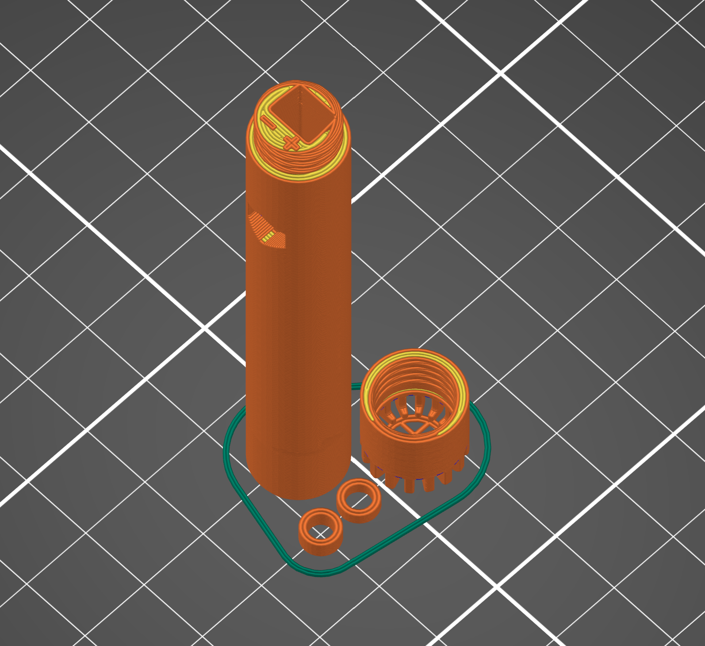
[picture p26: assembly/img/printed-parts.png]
sliced printed parts


The small features on the grille may result in stringing. As long as the grille threads properly onto the body, strings won't interfere with assembly or performance.

If you are using an alternate preamp filter configuration that doesn't use the switch, as described in the preamplifier section, there is a [version of the mic body with no hole or markings](stl/Body_no_switch.stl).

### 7. Install an O-ring in the grille

This step is optional. Sealing the mic capsule has almost no effect on the free field microphone response, but it does have a few small benefits. It ensures there is no air path around the mic capsule inside the body of the microphone, and keeps the grille from getting loose and needing to be tightened. A seal is required if you want to calibrate the microphone sensitivty using a pistonphone (or use it for any other pressure field application). Using an O-ring to seal the mic capsule results in significant twisting force on the soldered pins on the back of the capsule, so the pins must be reinforced with glue or the pads will be ripped off the capsule.

Using a pair of tweezers, insert one side of the O-ring into the grille. Get one part of the O-ring into the groove in the grille between the openings on the front of the grille and the threaded portion, then work from there around the edge inserting more of the O-ring until the entire O-ring seats into the groove.

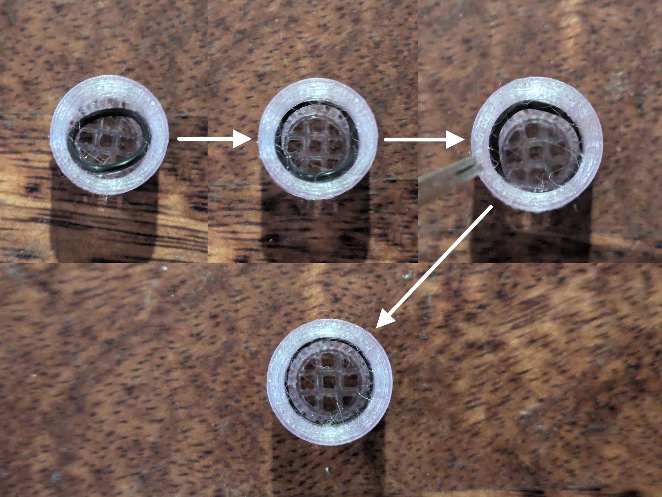
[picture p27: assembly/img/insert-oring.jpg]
install O-ring in grille


### 8. Final assembly

Insert the PCB into the mic body. It should only fit in one orientation and should have very little resistance the entire way until the flange on the mini XLR connector is seated on the back of the mic body. Insert the M3x8 screw through the top (thicker) spacer and insert the screw into the round hole in the mic body, through the hole in the PCB. Insert the bottom (thinner) spacer into the hexagonal hole in the mic body, around the screw, then insert the M3 hex nut and tighten the screw.

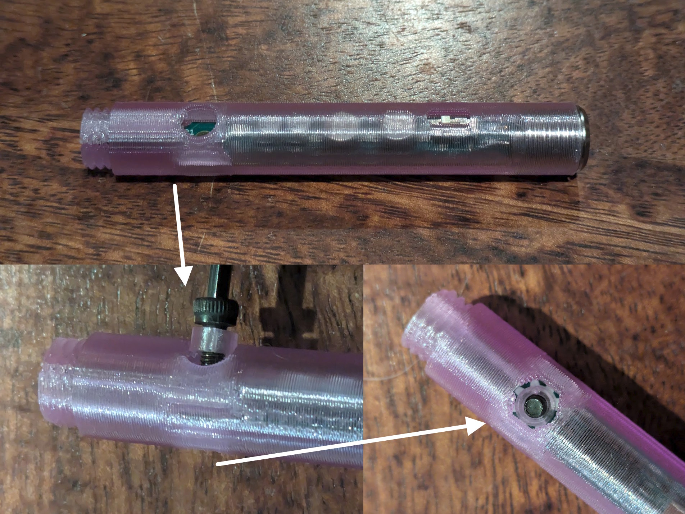
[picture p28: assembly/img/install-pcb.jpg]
install PCB


Insert the mic capsule pins into the opening in the front of the mic body. There are polarity markings modeled into the front face of the mic body, and (assuming you used the soldering jig to add the pins to the capsule) the capsule should be concentric with the mic body. Thread the grille around the capsule and onto the mic body and gently screw the grille in. If you are using an O-ring for sealing there will be a lot of resistance. If you are not using an O-ring there should be very little resistance. If you are not using an O-ring and you have not reinforced the mic capsule pins, any resistance could be pressure on the side of the mic capsule, with a very high risk of ripping the solder pads off the back of the capsule. Depending on print/assembly tolerances, the grille may not thread all the way onto the mic body, leaving a very small gap between the grille and the mic body.

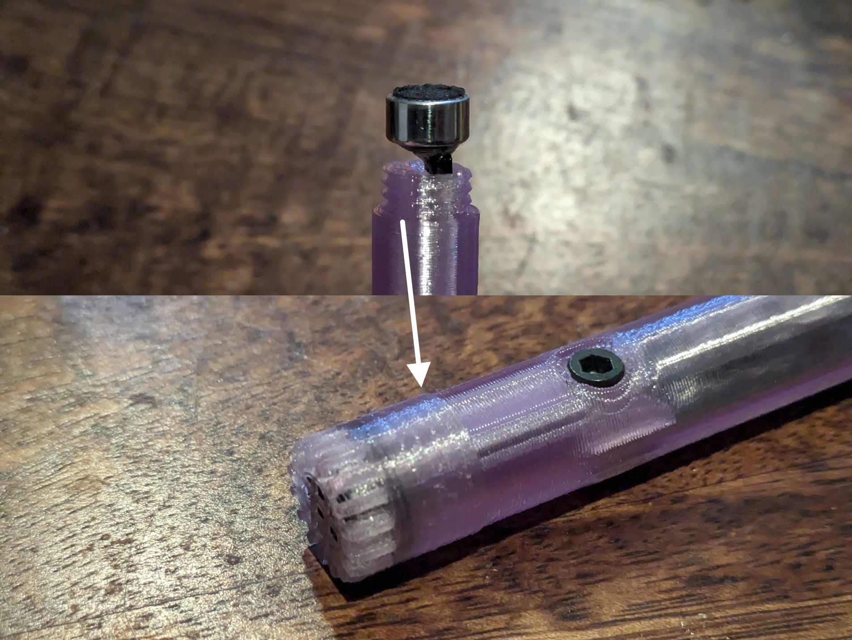
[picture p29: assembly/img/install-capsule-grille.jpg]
install the mic capsule and grille


<br>

## Mini-XLR adapter

The last piece of assembly is an adapter to connect the mini-XLR OpenRefMic to a standard XLR input. Commercial adapters are available, but are difficult to find and expensive. Creating your own adapter is as simple as removing the full size female XLR connector from a standard microphone cable and replacing it with a female mini-XLR connector (one option is listed in the [BOM](../Bill_of_materials.csv)).

A standard microphone cable will probably not fit through the narrow opening of the plastic shroud on the mini-XLR connector, but the shroud can be easily drilled out to widen the opening enough to fit the larger cable through. The conductors will also probably be thicker than intended for the mini-XLR solder tabs, so be sure to shield the wires from each other with heat shrink or tape.

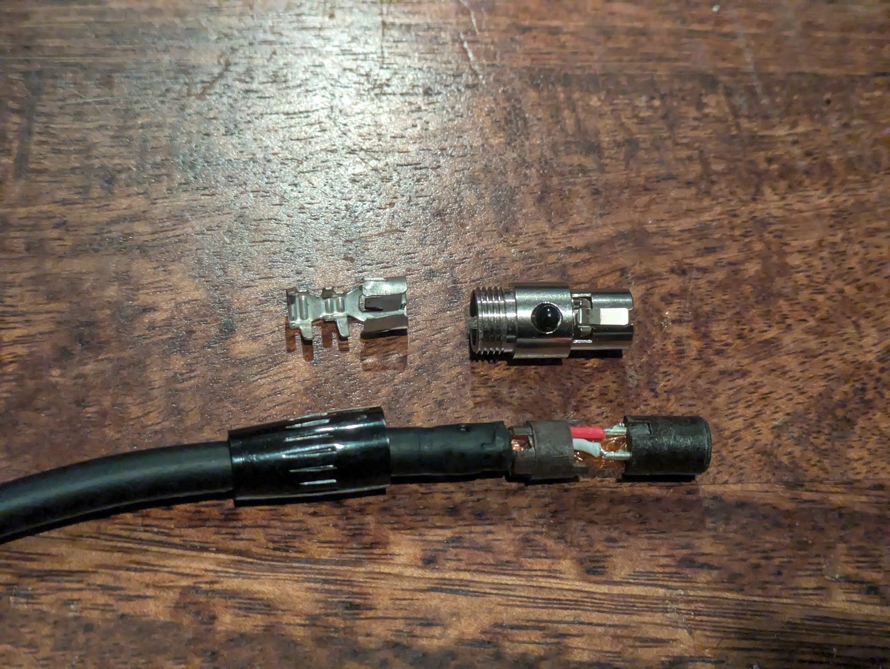
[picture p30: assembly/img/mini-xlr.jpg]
mini XLR cable


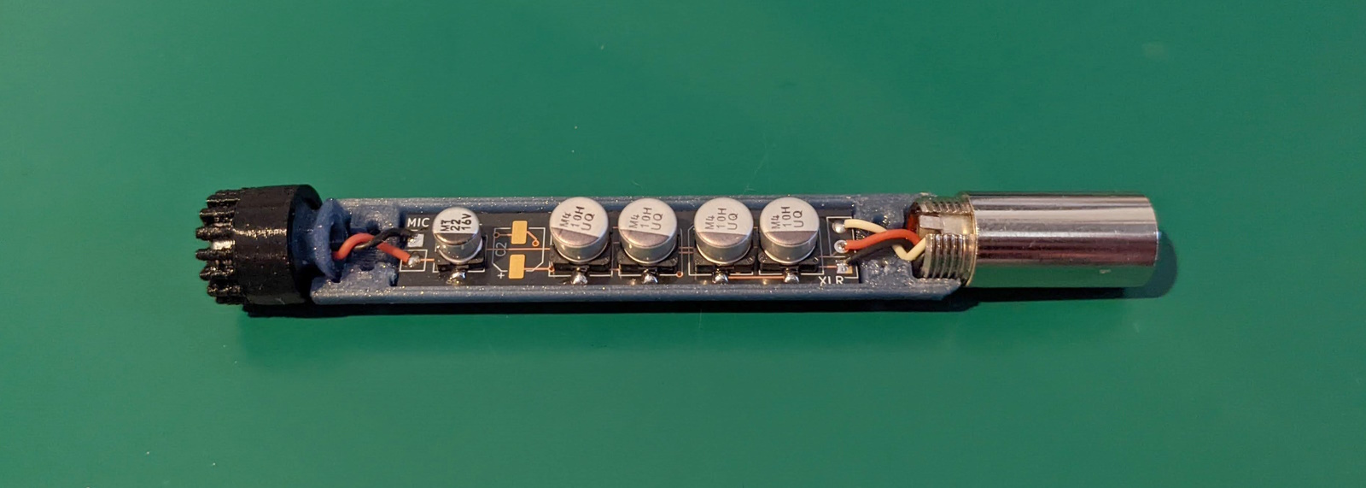
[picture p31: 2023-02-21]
img/bottom-assembly.jpg

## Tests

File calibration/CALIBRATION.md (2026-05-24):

# Calibration

The PUI AOM-5024L-HD-F-R electret microphone element was selected for OpenRefMic primarily for its very high SNR, but it has poor frequency response flatness compared to most electret microphones. Within the constraints of the hardware available for comparison, a reasonable correction curve has been derived that can be applied to match the AOM-5024L-HD-F-R high frequency response to within ~2dB of the response of comparable prosumer measurement microphones. The OpenRefMic v2 PCB includes a filter that can be applied directly in the microphone, avoiding the need for post-processing.

<br>

## Typical Performance

Due to unit to unit variability between mic capsules (and to a lesser extent component tolerances in the preamp), OpenRefMic sensitivtity and noise floor can vary by up to ±3dB. The following values have been measured from a single OpenRefMic prototype and can be used as approximate levels that can be used to get reasonably close for other OpenRefMics

Sensitivity at 1kHz, 1Pa/94dBSPL
- -20.7dBV
- 92.2mV

<br>

Signal to Noise Ratio relative to 94dBSPL(A-weighted)
- 78.2dB SNR

<br>

Noise Floor (A-weighted)
- 15.8dBA
- -98.9dBV
- 11.35uV

<br>

## Calibration files

Calibration files are available in several formats:

- [frequency-response.csv](frequency-response.csv) - Raw frequency response at 94dBSPL (1Pa), calibrated against a Listen SCM-2 reference microphone, 24 points per octave from 10Hz-20kHz with no smoothing. The ripples above ~13kHz are artefacts of the measurement setup, and it is not recommended to actually use this data to correct any measurements or recordings. This data is provided for reference only.

<br>

- [correction-curve.csv](correction-curve.csv) - Amplitude adjustments to apply to measurements taken with an OpenRefMic, 24 points per octave from 10Hz to 20kHz. This curve was derived by using a Monte Carlo optimization to match 2nd order filters to the inverse of the microphone's high frequency response.
    - How you use this correction curve depends on what software you are using it with. You may be able to import it directly, or you may need to interpolate the frequency points to match your measurement points. If your software does not allow importing you may need to export raw measurment data at the same frequency resolution as the correction curve and apply the curve to the output with an external tool (e.g. Excel)
    - For frequency-amplitude measurements like frequency responses and noise sprectra, the correction curve should be summed with the raw measurment.
    - For equalization of recordings, you can import the correction curve into any FIR filter (or similar effect) that allows you to use arbitrary EQ curves.

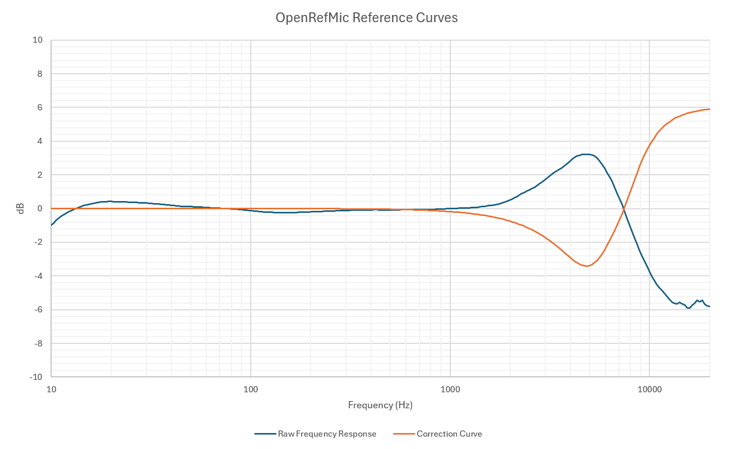
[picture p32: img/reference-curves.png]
reference curves


<br>

- [second-order-filters.txt](second-order-filters.txt) - Parameters and coefficients for filters at different sample rates that you can use to equalize recordings taken with an OpenRefMic. Only two filter stages are needed to correct the frequency response up to 20kHz, a shelving filter to recover frequencies above ~7kHz and a moderate notch to reduce a resonance around 5kHz.
  - You can input the filter parameters into any tool that implements 2nd-order IIR filters. The names for these filters vary from tool to tool. They may be labeled "biquad", "scientific filters", "parametric EQ", "analog filters", etc. The exact implementation might be different, so you should verify the filter response is consistent with correction-curve.csv.
  - Due to frequency warping effects, the exact filter values are slightly different at each sample rate. The values were derived using a Monte Carlo optimization process.
  - Recordings can be equalized using the command-line audio processing tool [SoX](http://sox.sourceforge.net/). For a recording at 48kHz the command would be:
    `sox <raw recording> <equalized recording> treble 5.94 6180 1.313q equalizer 7314 1.149q -6.12`

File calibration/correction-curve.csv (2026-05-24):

OpenRefMic correction curve
Hz | dB
10 | -1.80952E-05
10.2932245 | -1.91719E-05
10.59504705 | -2.03127E-05
10.90571978 | -2.15214E-05
11.2255022 | -2.28021E-05
11.55466142 | -2.4159E-05
11.8934724 | -2.55966E-05
12.24221814 | -2.71196E-05
12.60118997 | -2.87334E-05
12.97068773 | -3.04432E-05
13.35102006 | -3.22546E-05
13.74250467 | -3.4174E-05
14.14546857 | -3.62076E-05
14.56024836 | -3.83619E-05
14.98719051 | -4.06448E-05
15.42665165 | -4.30634E-05
15.87899886 | -4.56258E-05
16.34461001 | -4.83407E-05
16.82387401 | -5.12173E-05
17.3171912 | -5.42649E-05
17.82497367 | -5.7494E-05
18.34764556 | -6.09149E-05
18.88564347 | -6.45397E-05
19.4394168 | -6.83802E-05
20.00942812 | -7.24492E-05
20.59615356 | -7.67606E-05
21.20008324 | -8.13281E-05
21.82172161 | -8.61673E-05
22.46158794 | -9.12949E-05
23.12021672 | -9.67272E-05
23.79815811 | -0.000102483
24.4959784 | -0.000108581
25.21426049 | -0.000115043
25.95360437 | -0.000121888
26.71462762 | -0.000129141
27.49796594 | -0.000136826
28.30427366 | -0.000144968
29.1342243 | -0.000153594
29.98851112 | -0.000162733
30.86784773 | -0.000172417
31.77296863 | -0.000182677
32.7046299 | -0.000193547
33.66360976 | -0.000205064
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

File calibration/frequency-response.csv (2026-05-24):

OpenRefMic v2 average frequency response, normalized to 1kHz
Hz | dB
10 | -0.989527417
10.2932 | -0.842810054
10.595 | -0.70700336
10.9057 | -0.583453085
11.2255 | -0.470818153
11.5547 | -0.370118348
11.8935 | -0.2790559
12.2422 | -0.196458633
12.6012 | -0.120848742
12.9707 | -0.051084636
13.351 | 0.013589415
13.7425 | 0.073435518
14.1455 | 0.127056867
14.5602 | 0.174724333
14.9872 | 0.217169667
15.4267 | 0.254463449
15.879 | 0.287532828
16.3446 | 0.317390532
16.8239 | 0.343793774
17.3172 | 0.36625988
17.825 | 0.384925711
18.3476 | 0.399158258
18.8856 | 0.409048874
19.4394 | 0.414281435
20.0094 | 0.415456636
20.5962 | 0.413130586
21.2001 | 0.408597549
21.8217 | 0.40277305
22.4616 | 0.39638303
23.1202 | 0.389718812
23.7982 | 0.383286718
24.496 | 0.376782847
25.2143 | 0.369853038
25.9536 | 0.362951001
26.7146 | 0.355856015
27.498 | 0.348451761
28.3043 | 0.340558781
29.1342 | 0.33177238
29.9885 | 0.322239906
30.8678 | 0.311659173
31.773 | 0.299967151
32.7046 | 0.287736376
33.6636 | 0.274952808
34.6507 | 0.261283542
35.6668 | 0.24697987
36.7126 | 0.232481126
37.7891 | 0.217703132
38.8972 | 0.20285125
40.0377 | 0.188224734
41.2117 | 0.174170195
42.4202 | 0.160979728
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

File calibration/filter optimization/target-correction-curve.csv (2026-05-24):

OpenRefMic correction curve
Hz | dB
10 | 0
10.2932245 | 0
10.59504705 | 0
10.90571978 | 0
11.2255022 | 0
11.55466142 | 0
11.8934724 | 0
12.24221814 | 0
12.60118997 | 0
12.97068773 | 0
13.35102006 | 0
13.74250467 | 0
14.14546857 | 0
14.56024836 | 0
14.98719051 | 0
15.42665165 | 0
15.87899886 | 0
16.34461001 | 0
16.82387401 | 0
17.3171912 | 0
17.82497367 | 0
18.34764556 | 0
18.88564347 | 0
19.4394168 | 0
20.00942812 | 0
20.59615356 | 0
21.20008324 | 0
21.82172161 | 0
22.46158794 | 0
23.12021672 | 0
23.79815811 | 0
24.4959784 | 0
25.21426049 | 0
25.95360437 | 0
26.71462762 | 0
27.49796594 | 0
28.30427366 | 0
29.1342243 | 0
29.98851112 | 0
30.86784773 | 0
31.77296863 | 0
32.7046299 | 0
33.66360976 | 0
34.65070926 | 0
35.66675294 | 0
36.7125895 | 0
37.78909255 | 0
38.89716131 | 0
40.03772136 | 0
41.21172543 | 0
42.42015417 | 0
43.664017 | 0
44.94435293 | 0
46.26223145 | 0
47.6187534 | 0
49.01505189 | 0
50.45229328 | 0
51.9316781 | 0
53.45444211 | 0
55.0218573 | 0
56.63523293 | 0
58.29591669 | 0
60.00529577 | 0
61.76479802 | 0
63.5758932 | 0
65.44009412 | 0
67.35895798 | 0
69.33408762 | 0
71.36713291 | 0
73.45979206 | 0
75.61381311 | 0
77.83099533 | 0
80.11319076 | 0
82.46230575 | 0
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

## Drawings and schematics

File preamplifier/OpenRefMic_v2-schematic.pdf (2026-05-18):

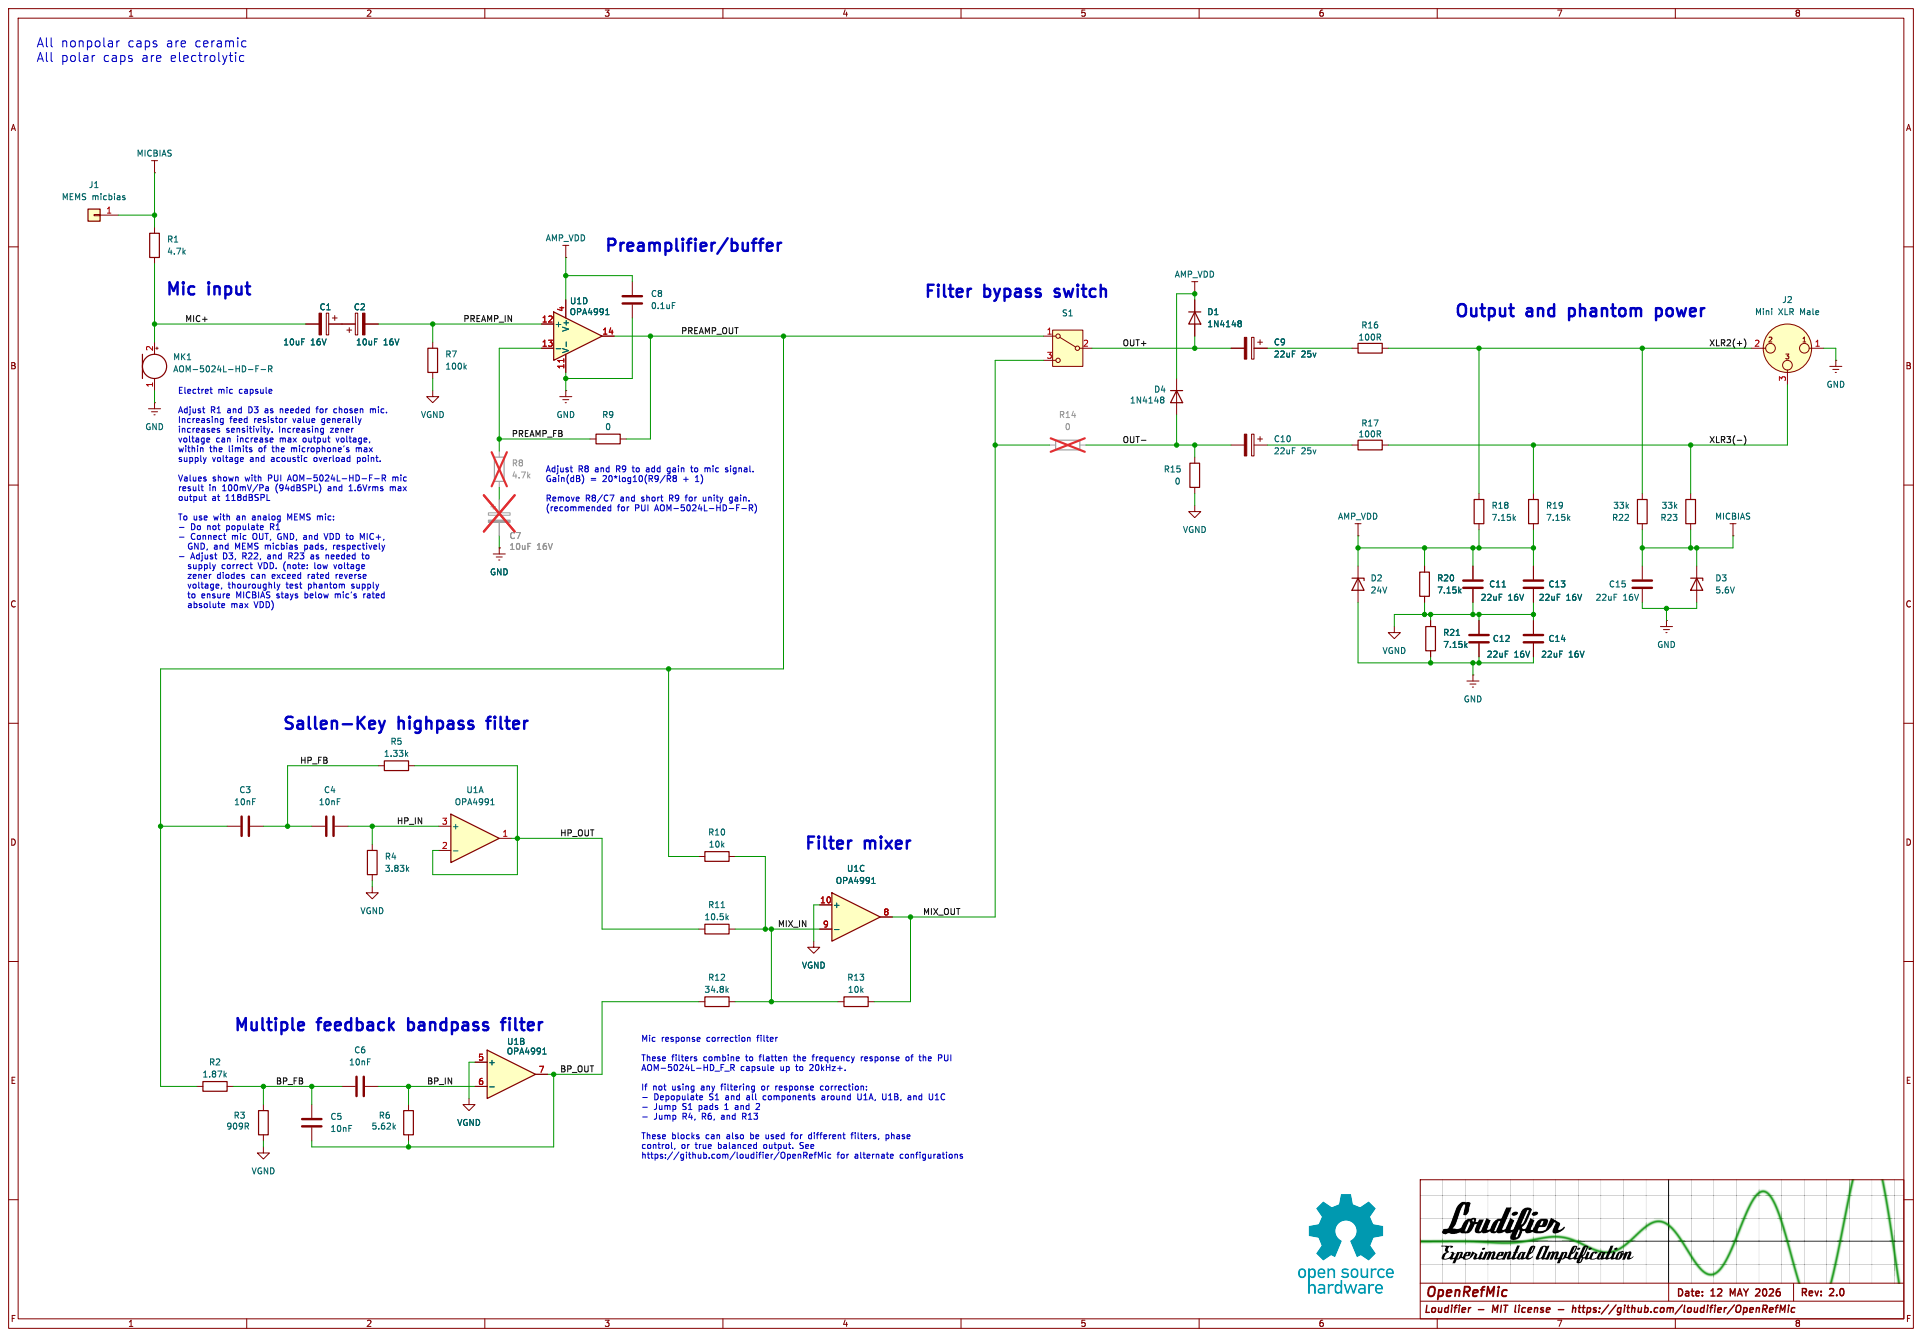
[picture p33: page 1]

All polar caps are electrolytic

J2 Mini XLR Male GND

Output and phantom power

Adjust R1 and D3 as needed for chosen mic.

Adjust R8 and R9 to add gain to mic signal.

- Adjust D3, R22, and R23 as needed to
supply correct VDD. (note: low voltage
zener diodes can exceed rated reverse
to ensure MICBIAS stays below mic's rated

Multiple feedback bandpass filter

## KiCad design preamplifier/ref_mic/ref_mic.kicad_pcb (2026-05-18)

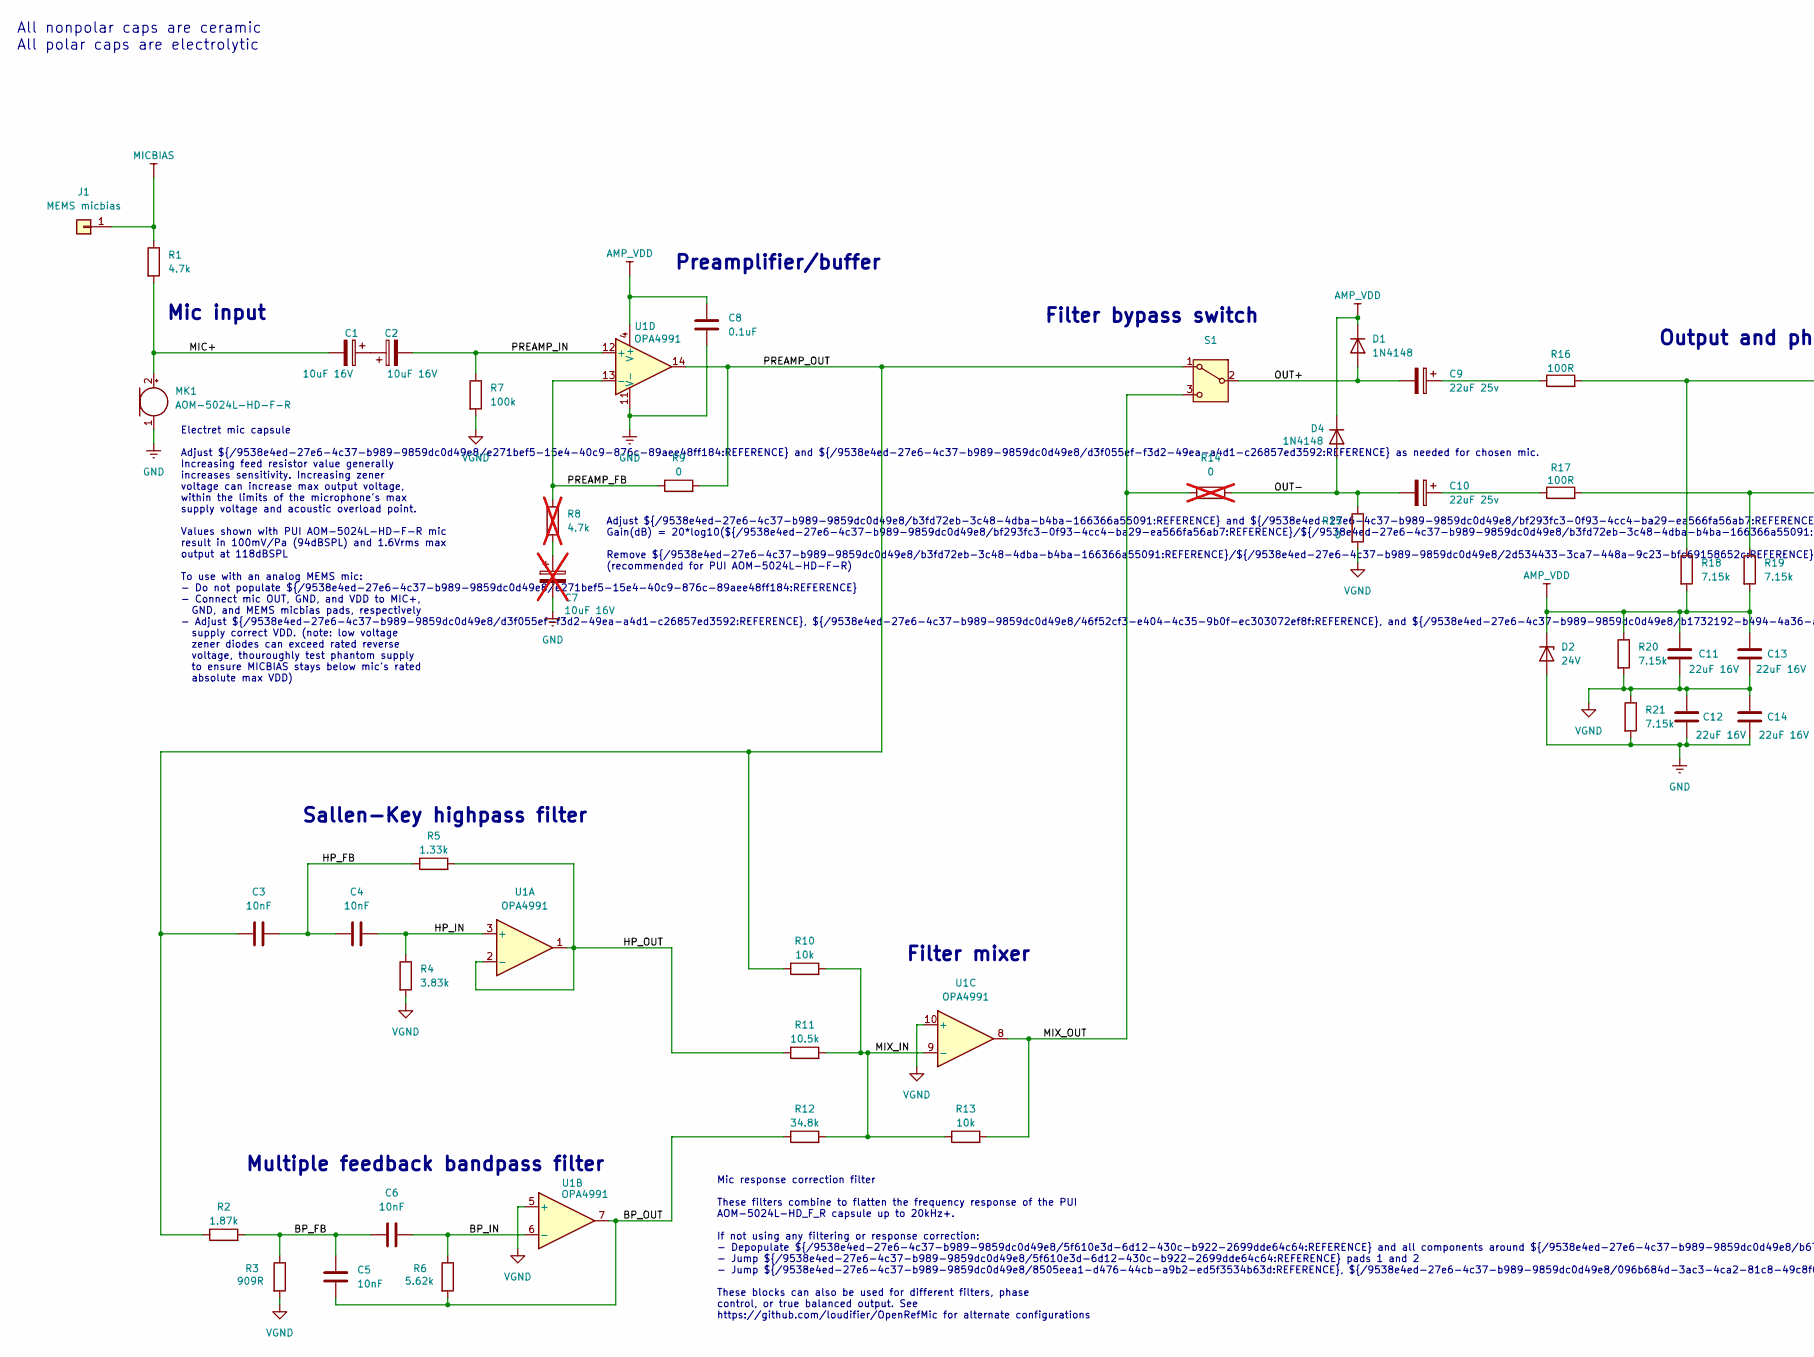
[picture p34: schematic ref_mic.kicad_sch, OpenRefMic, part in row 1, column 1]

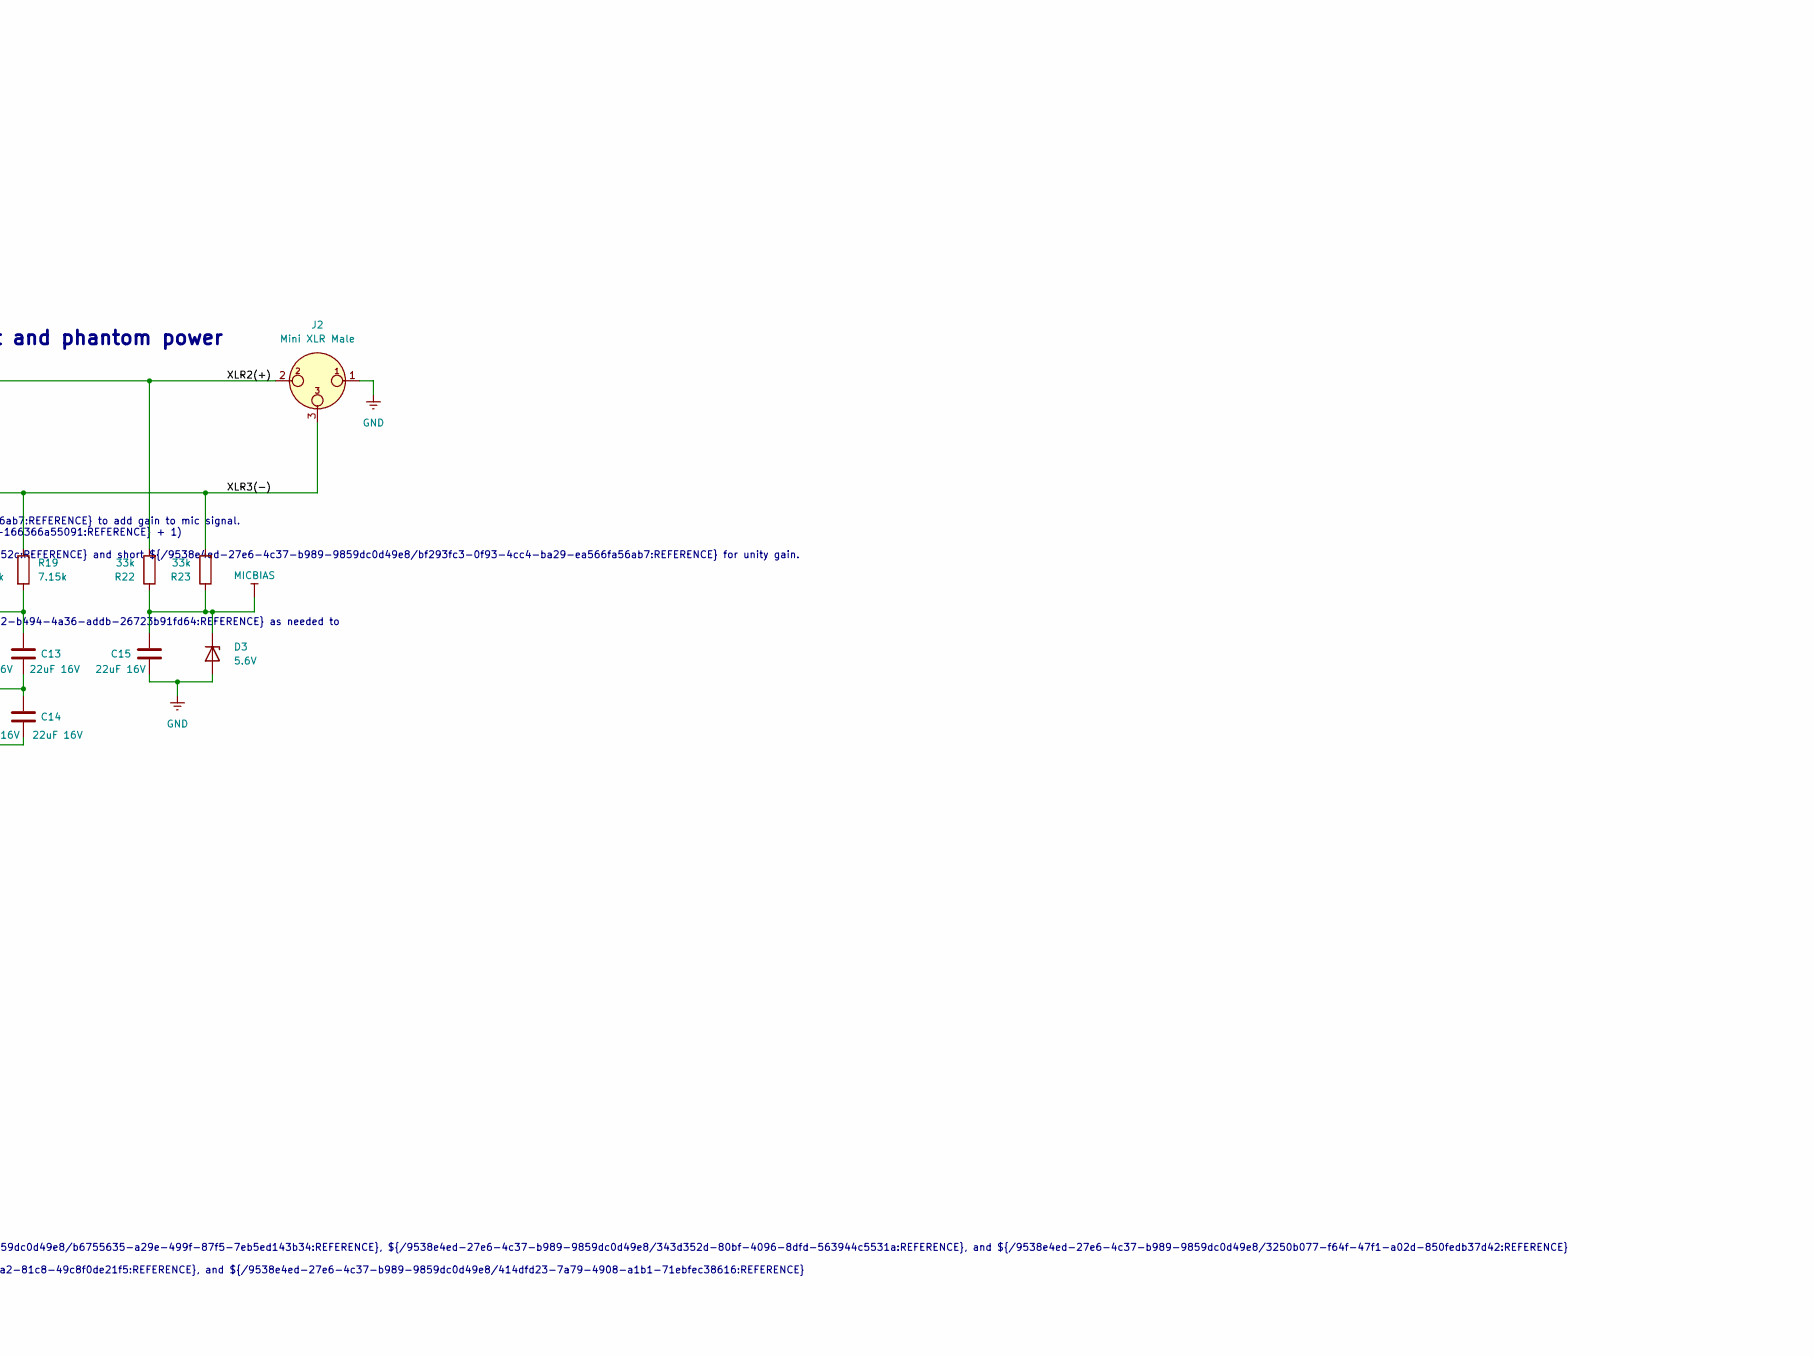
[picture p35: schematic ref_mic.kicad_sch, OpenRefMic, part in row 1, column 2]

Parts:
C1, C2: 10uF 16V; CP_Elec_4x4.5; LCSC_Part_Number Lelon VSS100M1CTR-0404
C3, C4, C5, C6: 10nF; C_0402_1005Metric; LCSC_Part_Number YAGEO CC0402KRX7R9BB103
C7: 10uF 16V; CP_Elec_4x4.5; DigiKey_Part_Number UZG1C100MCL1GB; not fitted
C8: 0.1uF; C_0402_1005Metric; LCSC_Part_Number YAGEO CC0402KRX5R9BB104
C9, C10: 22uF 25v; CP_Elec_6.3x4.5; LCSC_Part_Number Nichicon UZG1E220MCL1GB
C11, C12, C13, C14, C15: 22uF 16V; C_1210_3225Metric_0.95mm-height; DigiKey_Part_Number EMK325BJ226MD-T
D1, D4: 1N4148; D_SOD-523; LCSC_Part_Number MCC 1N4148X-TP
D2: 24V; D_SOD-523; LCSC_Part_Number Diodes Incorporated BZT585B24T-7
D3: 5.6V; D_SOD-523; LCSC_Part_Number Diodes Incorporated BZT52C5V6T-7
J1: MEMS micbias; SolderWire-0.1sqmm_1x01_D0.4mm_OD1mm
J2: Mini XLR Male; Switchcraft_T3BM_edgemount; LCSC_Part_Number Switchcraft TB3M (not normally stocked)
MK1: AOM-5024L-HD-F-R; PinSocket_1x02_P2.54mm_Horizontal; LCSC_Part_Number PUI Audio, Inc. AOM-5024L-HD-F-R (not n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
R1: 4.7k; R_0402_1005Metric; LCSC_Part_Number YAGEO RC0402FR-074K7L
R2: 1.87k; R_0402_1005Metric; LCSC_Part_Number YAGEO RC0402FR-131K87L
R3: 909R; R_0402_1005Metric; LCSC_Part_Number YAGEO RC0402FR-07909RL
R4: 3.83k; R_0402_1005Metric; LCSC_Part_Number YAGEO RC0402FR-073K83L
R5: 1.33k; R_0402_1005Metric; LCSC_Part_Number YAGEO RC0402FR-131K33L
R6: 5.62k; R_0402_1005Metric; LCSC_Part_Number YAGEO RC0402FR-075K62L
R7: 100k; R_0402_1005Metric; LCSC_Part_Number YAGEO RC0402FR-07100KL
R8: 4.7k; R_0402_1005Metric; LCSC_Part_Number YAGEO RC0402FR-074K7L; not fitted
R9, R15: 0; R_0402_1005Metric; LCSC_Part_Number YAGEO RC0402JR-070RL
R10, R13: 10k; R_0402_1005Metric; LCSC_Part_Number YAGEO RC0402FR-0710KL
R11: 10.5k; R_0402_1005Metric; LCSC_Part_Number YAGEO RC0402FR-0710K5L
R12: 34.8k; R_0402_1005Metric; LCSC_Part_Number YAGEO RC0402FR-0734K8L
R14: 0; R_0402_1005Metric; LCSC_Part_Number YAGEO RC0402JR-070RL; not fitted
R16, R17: 100R; R_0402_1005Metric; LCSC_Part_Number YAGEO RC0402FR-07100RL
R18, R19, R20, R21: 7.15k; R_0402_1005Metric; LCSC_Part_Number YAGEO RC0402FR-077K15L
R22, R23: 33k; R_0402_1005Metric; LCSC_Part_Number YAGEO RC0402FR-0733KL
S1: CL-SB-12B-01T; CL-SB-12B-01_NDC; DigiKey_Part_Number CL-SB-12B-01T
U1: OPA4991; SO-14_3.9x8.65mm_P1.27mm; LCSC_Part_Number TI OPA4991IDR

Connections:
/BP_FB: C5.2, C6.1, R2.2, R3.1
/BP_IN: C6.2, R6.1, U1.6 (-)
/BP_OUT: C5.1, R6.2, R12.1, U1.7
/HP_FB: C3.2, C4.1, R5.1
/HP_IN: C4.2, R4.1, U1.3 (+)
/HP_OUT: R5.2, R11.1, U1.1, U1.2 (-)
/MIC+: C1.2, MK1.2 (+), R1.2
/MIX_IN: R10.2, R11.2, R12.2, R13.1, U1.9 (-)
/MIX_OUT: R13.2, R14.1, S1.3 (C), U1.8
/OUT+: C9.2, D1.2 (A), S1.2 (B)
/OUT-: C10.2, D4.2 (A), R14.2, R15.1
/PREAMP_FB: R8.1, R9.1, U1.13 (-)
/PREAMP_IN: C2.2, R7.1, U1.12 (+)
/PREAMP_OUT: C3.1, R2.1, R9.2, R10.1, S1.1 (A), U1.14
/XLR2(+): J2.2, R16.2, R18.1, R22.2
/XLR3(-): J2.3, R17.2, R19.1, R23.2
AMP_VDD: C8.1, C11.1, C13.1, D1.1 (K), D2.1 (K), D4.1 (K), R18.2, R19.2, R20.1, U1.4 (V+)
GND: C7.2, C8.2, C12.2, C14.2, C15.2, D2.2 (A), D3.2 (A), J2.1, MK1.1 (-), R21.2, U1.11 (V-)
MICBIAS: C15.1, D3.1 (K), J1.1, R1.1, R22.1, R23.1
unnamed: C1.1, C2.1
unnamed: C7.1, R8.2
unnamed: C9.1, R16.1
unnamed: C10.1, R17.1
VGND: C11.2, C12.1, C13.2, C14.1, R3.2, R4.2, R7.2, R15.2, R20.2, R21.1, U1.5 (+), U1.10 (+)

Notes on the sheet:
Multiple feedback bandpass filter
All nonpolar caps are ceramic All polar caps are electrolytic
Sallen-Key highpass filter
Mic input
Mic response correction filter These filters combine to flatten the frequency response of the PUI AOM-5024L-HD_F_R capsule up to 20kHz+. If not using any filtering or response correction: - Depopulate ${/9538e4ed-27e6-4c37-b989-9859dc0d49e8/5f610e3d-6d12-430c-b922-2699dde64c64:REFERENCE} and all co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
Preamplifier/buffer
Adjust ${/9538e4ed-27e6-4c37-b989-9859dc0d49e8/b3fd72eb-3c48-4dba-b4ba-166366a55091:REFERENCE} and ${/9538e4ed-27e6-4c37-b989-9859dc0d49e8/bf293fc3-0f93-4cc4-ba29-ea566fa56ab7:REFERENCE} to add gain to mic signal. Gain(dB) = 20*log10(${/9538e4ed-27e6-4c37-b989-9859dc0d49e8/bf293fc3-0f93-4cc4-ba29-e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
Output and phantom power
Electret mic capsule Adjust ${/9538e4ed-27e6-4c37-b989-9859dc0d49e8/e271bef5-15e4-40c9-876c-89aee48ff184:REFERENCE} and ${/9538e4ed-27e6-4c37-b989-9859dc0d49e8/d3f055ef-f3d2-49ea-a4d1-c26857ed3592:REFERENCE} as needed for chosen mic. Increasing feed resistor value generally increases sensitivity. I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
Filter bypass switch
Filter mixer

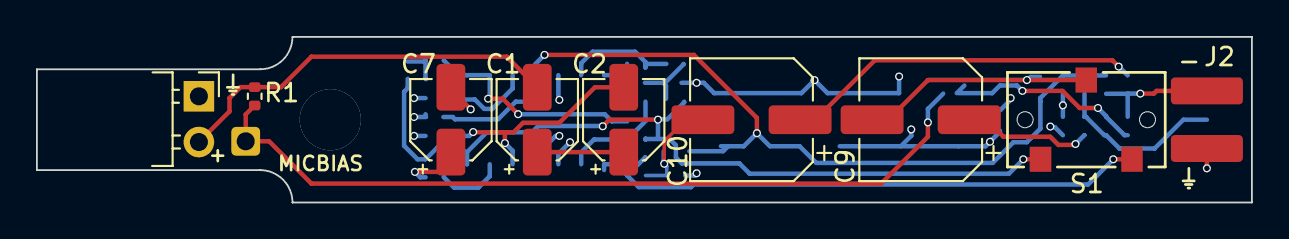
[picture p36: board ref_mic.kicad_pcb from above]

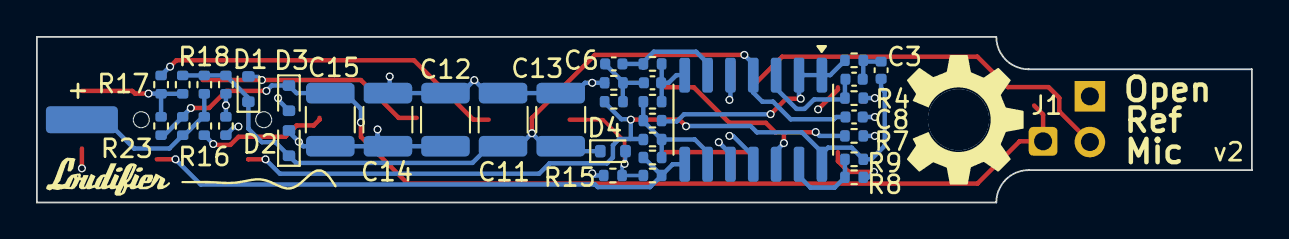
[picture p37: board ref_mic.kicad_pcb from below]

Board: 4 copper layers, 67.5 x 9.2 mm, 47 parts (38 on the bottom side), 24 nets.

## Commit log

2022-06-19 initial commit
    Majority of initial project and documentation included. Some pieces missing, construction photos, measurement setup and tools descriptions, etc.
    [4191_frequency-response_90-deg.csv, 4191_frequency-response_94dBSPL.csv, Bill_of_materials.csv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]
2022-08-01 Add R3 to BOM
    [Bill_of_materials.csv]
2022-08-01 Add C3 to BOM
    [Bill_of_materials.csv]
2022-08-13 Update Bill_of_materials.csv
    Moved C3, R3 to optional components section at bottom of BOM. Cleaned up extraneous commas
    [Bill_of_materials.csv]
2025-03-02 add missing v1 gerbers
    [ref_mic-B_Cu.gbr, ref_mic-B_Mask.gbr, ref_mic-B_Paste.gbr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]
2025-03-02 Initial v2 schematic, including high frequency correction filter for specified mic, library for slide switch. Update project to KiCAD 9.0 and change DNPs to use built in DNP feature.
    [ref_mic.kicad_sch]
2026-01-06 Bulk of v2 updates, before assembly and testing new design - KiCAD project - gerber outputs - schematic PDF - mechanical design (Fusion project, STEP assembly, STL outputs)
    [Bill_of_materials.csv, Body bottom.stl, Body top.stl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]
2026-01-07 add interactive BOM
2026-02-28 major v2 updates
    fixes based on initial v2 PCB build
    - R6 corrected to 8.06k
    - Replaced opamp with OPA4991
    - Adjust phantom power resistor values to optimize opamp Vdd
    - Connect R15 to VGND to avoid exceeding C10 voltage rating
    - Increase values of input AC-coupling caps, output caps, phantom power caps, decrease output series resistors. Reduces low frequency rolloff
    - Add D4 for alternate configs where In- is connected to an opamp output
    - Improved PCB layout
    - Improved CAD design, add soldering jig
    - Add 3MF with print settings for grille and body
    Update preamp documentation, add instructions for no/alternate filtering configs
    [Bill_of_materials.csv, Body.stl, Body_no_switch.stl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]
2026-03-19 increase mic body clearance for taller caps
    [Body.stl, OpenRefMic_v2.f3d, print settings.3mf]
2026-05-18 major v2 updates
    Likely the final versions of v2 design files
    - updated CAD. Small tweaks to spacers, modeled in grille openings (instead of relying on slicer settings), increased room for taller caps, increased clearance for header pins on bottom of PCB
    - Updated EQ component values based on measurements of several prototypes (original v1 prototype capsule response deviated significantly from other 5+ other capsules tested).
    - Added PCB thickness requirement note to preamp doc and directly on fab layer of layout
    - Updated all KiCAD files, gerber outputs, schematic outputs, etc.
    - updated readme, preamp docs
    [Bill_of_materials.csv, Grille.stl, bottom spacer.stl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]
2026-05-24 Update assembly instructions
2026-05-24 update calibration for v2
    [4191_frequency-response_90-deg.csv, 4191_frequency-response_94dBSPL.csv, EMM-6_frequency-response_94dBSPL.csv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]
2026-06-22 add input curve and global gain options to filter optimization

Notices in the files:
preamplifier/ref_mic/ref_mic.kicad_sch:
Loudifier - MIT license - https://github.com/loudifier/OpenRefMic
